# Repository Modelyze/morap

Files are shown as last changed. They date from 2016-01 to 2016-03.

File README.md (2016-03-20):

# MORAP: a Modular Robotic Arm Platform

### Contributors
* Viktor Kozma, KTH Royal Institute of Technology, vkozma@kth.se
* David Broman, KTH Royal Institute of Technology, dbro@kth.se

## Introduction
The MORAP system is designed to be a modular robotic arm for research purposes. It's modular in a way that modules can be designed and added or interchanged to achieve new configurations.

It is designed together with a Modelyze modeling library that allows building and simulating arm configurations, giving the user the ability to design and evaluate designs in software.

## Overall Design
The system is designed as a distributed system where each component is communicating on a standardized central data bus. This means that it's trivial to add other modules or sensors to the system.

The system has one master which controls all of the individual sub-systems and handles communication with the user. This master controller can be anything, a microcontroller, Arduino, Raspberry pi etc. The user programs this controller to fulfill specific tasks relevant to their intended application.

## Software Design
For actuation each joint have built in control electronics and tuning algorithms, providing an intuitive and easy way to control the system. The communication protocol is listed in [here](./api/) and an API implementation on a PIC32 microcontroller is listed in section [here](./api/pic32/).

Some software examples are listed [here](./applications).

## Hardware Design
The hardware is divided into joints, links and end-effectors. 

The joints provide actuation and control electronics, allowing the user to control them in multiple ways. There are also be free-running joints, like pendulums, which allows for modeling and controlling complex systems. The joints designs are found [here](./joints).

Links are the connection elements between the joints and can be anything. In this application 20x20 mm aluminum profiles are used. [possible pics?].

End-effectors are devices meant to interact with the real world. They're attached to the end of the arm and can come in different shapes, like pens or claws. Some designs can be found [here](./end-effectors).

The manufacturing process used to fabricate the necessary parts are 3d-printing.

## The Simplified BSD License

Copyright (c) 2016, Viktor Kozma and David Broman

All rights reserved.

Redistribution and use in source and binary forms, with or without
modification, are permitted provided that the following conditions are
met:

1. Redistributions of source code must retain the above copyright
notice, this list of conditions and the following disclaimer.

2. Redistributions in binary form must reproduce the above copyright
notice, this list of conditions and the following disclaimer in the
documentation and/or other materials provided with the distribution.

THIS SOFTWARE IS PROVIDED BY THE COPYRIGHT HOLDERS AND CONTRIBUTORS
"AS IS" AND ANY EXPRESS OR IMPLIED WARRANTIES, INCLUDING, BUT NOT
LIMITED TO, THE IMPLIED WARRANTIES OF MERCHANTABILITY AND FITNESS FOR
A PARTICULAR PURPOSE ARE DISCLAIMED. IN NO EVENT SHALL THE COPYRIGHT
HOLDER OR CONTRIBUTORS BE LIABLE FOR ANY DIRECT, INDIRECT, INCIDENTAL,
SPECIAL, EXEMPLARY, OR CONSEQUENTIAL DAMAGES (INCLUDING, BUT NOT
LIMITED TO, PROCUREMENT OF SUBSTITUTE GOODS OR SERVICES; LOSS OF USE,
DATA, OR PROFITS; OR BUSINESS INTERRUPTION) HOWEVER CAUSED AND ON ANY
THEORY OF LIABILITY, WHETHER IN CONTRACT, STRICT LIABILITY, OR TORT
(INCLUDING NEGLIGENCE OR OTHERWISE) ARISING IN ANY WAY OUT OF THE USE
OF THIS SOFTWARE, EVEN IF ADVISED OF THE POSSIBILITY OF SUCH DAMAGE.

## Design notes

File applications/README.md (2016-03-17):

# Applications using a PIC32 microcontroller

Some example applications using the PIC32 API. These applications are
implemented and tested on the ChipKIT UNO32 development board.

## Available applications
The following applications can be opened as MPLAB projects:

[Potentiometer control](./potentiometer_control) is a simple
application where a button can be used to turns on/off one or two
motors. Each motor can be controlled by a separate potentiometer.

[Draw test](./draw_test) performs a simple control sequence in which
it positions an optional pen end-effector at three different
angles. This allows the user to evaluate the repeatability of the
system and to identify potential drifts in the encoders. If two motors are
found on the system, it will use both for the control sequence.

[Data logger](./data_logger) generates log data that can be used for
parameter extraction.  When using the application, save the log data
data and run the appropriate [matlab
scripts](../joints/dc-motor-joint/software/matlab).

[Inverse kinematics](./inverse_kinematics) is an application for
controlling a 2D robotic arm with two joints. The user supplies an x-y
coordinate and it calculates the required angles to reach that
position. It also comes with an preliminary implementation of a path
following algorithm in which the user can define a path that the arm
should follow. This application is still work in progress.

[Inverted pendulum](./pendulum) is a work-in-progress application that tries to
balance an inverted pendulum. It utilizes a
MPU9150 IMU for measuring the angle of the pendulum and is
controlled by a state-feedback controller.

In most of the applications you can change some definitions to change the
identifiers of the target motors or the arm lengths. More information is available at the beginning of each main source file.

## Installation

To run the applications above, you need to download and install the following development environment and compiler:

* [MPLAB IDE](http://www.microchip.com/mplab/mplab-x-ide). This is the main development environment for the PIC32 microprocessors from Microchip.
* [XC32 compiler](http://www.microchip.com/mplab/compilers). The main cross compiler. There is a free compiler version available. NOTE! If you need to program the PIC24 controller on the motor joint, you also need to download the XC16 compiler.
* [PIC32 Peripheral Library](http://www.microchip.com/SWLibraryWeb/product.aspx?product=PIC32%20Peripheral%20Library). This library is necessary if you use XC32 compiler 1.4 or later.

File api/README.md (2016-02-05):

# APIs for Controlling the Robotic Arm

This section contains the API for controlling the robotic arm as well as information on how it works so it can be ported to other platforms.

## Available Applications
An API has been developed for a PIC32 processor, or more specifically the PIC32MX320F128 equipped on a uno32, an arduino compatible development board. This API can be found [here](./pic32).

## How it Works
The communication protocol works on an I2C bus [link to wiki?], a serial communication protocol, running at 100 kHz. The I2C protocol is a single master protocol in which a master can initiate communication and write or request data from an addressable slave. The system can address up to 128 different units (but in practice some of these are reserved resulting in 112 practical addresses), allowing for many different subsystems to be included on the bus. 

Each joint and end-effector has an unique address allowing the master to address individual modules. If the addressed slave exists and acknowledges its existence on the bus the master starts to write data to the slave one byte at a time. A master can also read data from a slave, however such a read operation is an individual event so the master usually has to specify what data it wants to read by writing that information to the slave before requesting a read operation.

As this is a standardized protocol peripheral hardware, for example sensors, can be easily included in the system.

## Communication Protocol
In order for the slave to know what type of data the master writes the first byte sent after the address is an identifier. For some commands, like disabling the motors or calibrating the encoders, only requires this identifier to take effect. If additional data is needed, for example setting reference points for the controller, it is provided after the identifier with data-types larger than one byte sent with LSB first [check].

When a read operation is performed on a node it will start to return data. But to define what data it will return by first writing the specified read-mode (id 128+ in the table below) before starting to request data.

A table containing the identifiers, their purpose and format (purpose(variable type)(nr of bytes)) (the identifier has the variable type (uint8)) are located below:

id | purpose | format 
---------: | :---------- | :----------- 
0   | disable motors | id(1) 
1   | set position reference point | id(1)-pos_ref(float)(4) 
2   | set speed reference point | id(1)-speed_ref(float)(4) 
3   | set drive voltage | id(1)-voltage(float)(4) 
14  | disable brake | id(1) 
15  | enable brake | id(1) 
16  | calibrate encoder to zero | id(1) 
17  | calibrate encoder to supplied angle | id(1)-angle(float)(4) 
31  | set encoder calibration status to unknown | id(1) 
32  | program new control parameters | see next section 
33  | set control parameters to default values | id(1) 
34  | tune control parameters | see next section 
128 | next read operation will return the angle (float(4)) | id(1) 
129 | next read operation will return the position reference (float(4)) | id(1) 
130 | next read operation will return the speed reference (float(4)) | id(1) 
131 | next read operation will return the motor status (byte(1)) | id(1) 
132 | next read operation will return the controller programming status (byte(1)) | id(1) 
133 | next read operation will return the applied voltage (float(4)) | id(1) 
134 | next read operation will return the current (float(4)) | id(1) 
136 | next read operation will return the address of the node (byte(1)) | id(1) 

Potential returns for the motor status are as follows:

return value | meaning
---------: | :---------
1 | enabled
2 | disabled
3 | needs encoder calibration

Potential returns for the controller programming status are:

return value | meaning
----------: | :------------
1 | nothing has been programmed
2 | programming successful
3 | programming failed

## Programming the Control Variables
The controller is described in the [matlab](../joints/dc-motor-joint/software/matlab) section. There are three different ways to program the controller with new control parameter.

Send the control parameters directly (id = 32). This is done by sending all the parameters containted in the discrete controller directly. The format looks like this: 
```
id(1) - cMode(uint8)(1) - Fs(uint16)(2) - nd(uint8)(1) - d(float[nd])(nd*4) - 
  nc(uint8)(1) - c(float[nc])(nc*4) - nf(uint8)(1) - f(float[nf])(nf*4) - 
  I(float)(4) - checksum(uint8)(1)
```

The checksum is calculated by the following psuedocode:
```c
unsigned int sum = sum(control_params); // the sum of all bytes sent (excluding the id)
while (sum >> 8)
  sum = (sum >> 8) + (sum & 0xFF);
unsigned char checksum = ~((unsigned char) sum);
```

This approach is useful when you want to really know what each joint are doing, for example when performing simulations that should be compared to reality.

The motor node can also tune themselves when provided with tuning variables (id = 34). The formatting of this message looks like:
```
id(1) - controller_type(uint8)(1) - inertia(float)(4) - closed_loop_pole(float)(4)
```

The controller type can be be one of the following values:

| value | controller |
| ---: | :--- |
| 0 | PD position controller |
| 1 | PID position controller |
| 2 | PI speed controller |

The inertia is the inertia that the controller designs itself around.

The closed loop pole is the pole of the controller which determines how fast the controller is. It should be < 0 and the smaller it is the faster the controller becomes.

After performing any of these commands read the programming status after to ensure that they where programmed successfully.

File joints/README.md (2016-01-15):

# Joints

Joints is in this regard the connections between each of the links.

## Connecting the Elements Together
These can be connected together in different way with the links.
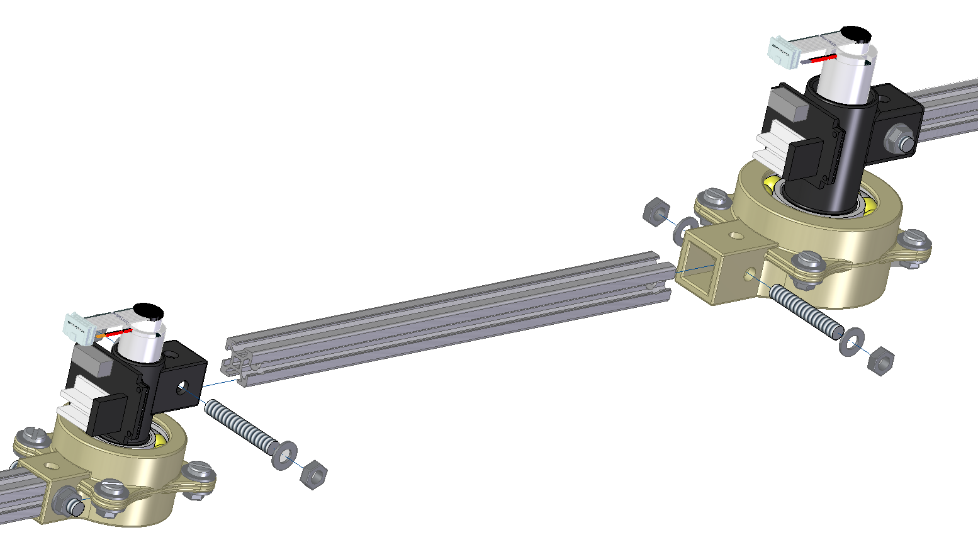
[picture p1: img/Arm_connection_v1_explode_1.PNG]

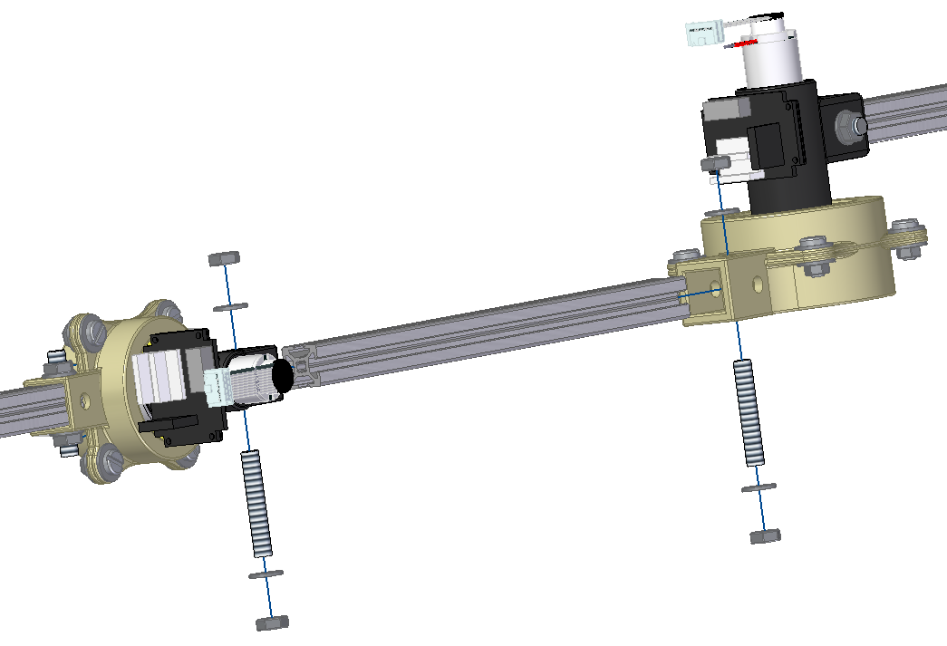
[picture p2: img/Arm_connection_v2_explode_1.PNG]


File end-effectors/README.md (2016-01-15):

# Different End Effectors Developed for the Robotic Arm

Contains different end-effectors capabale of mounting to the arm and interfacing with software.

## Making you own
**IMPORTANT. WHEN CONNECTING END EFFECTORS TO THE DATA BUS THE I2C LINES NEEDS TO WORK ON A 3.3 VOLT VOLTAGE LEVEL. OTHERWISE THE MOTOR CONTROLLING MICROCHIPS WILL BE FRIED.**  

This can be done through using chip that works on a 3.3 volt voltage level or using level shifters.

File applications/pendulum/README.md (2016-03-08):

# Inverted Pendulum

To get the inverted pendulum application up and running, please do the following.

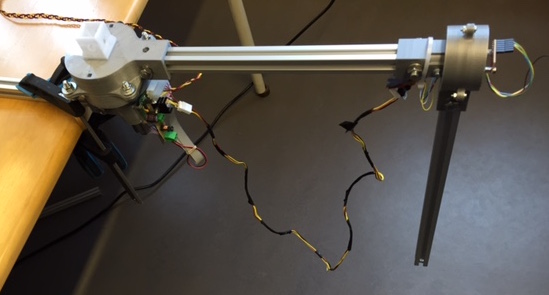
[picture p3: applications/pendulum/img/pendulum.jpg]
Example showing how the pendulum can be assembled
1. Connect one [motor joint](../../joints/dc-motor-joint) and a free-running [pendulum joint](../../joints/pendulum-joint) according to the picture below. 

2. Download and install the development environment ([see this page](../))

3. Open the project file applications/pendulum. Make sure that the project settings is correct and that you are using the right programmer (default is chipKITProgrammer).

4. Make sure that the supply voltage to the power is 24V. Reset the ChipKIT board and make sure that after the yellow LED is done blinking no LED should be lit up. If any of the leds are lit the following could be the issue:
    - Yellow LED stays lit: The I2C bus is hung up
    - Red LED stays lit: No connection to IMU found

5. Put the pendulum link in upright position. If the application works, the inverted pendulum should now stabilize. 

## Controller programming
A MATLAB script for generating control parameters are found [here](../../joints/dc-motor-joint/software/matlab) labeled "furuta_controller.m".

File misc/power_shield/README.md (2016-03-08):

# Power Shield for UNO32
A power shield designed to fit on an UNO32 designed to take input from two 4 mm lab cables, convert it to 5V and 3.3V and outputs it to two 6-pin connectors compatible with the standard connectors on the motor control chips.

Contains both Gerber and eagle source files

## Functions
* Inputs selectable voltage Vcc (>6V) through two 4 mm lab cables (Vcc and GND)
* Converts Vcc to 5V and 3.3V using two switching regulators
* Outputs Vcc, 5V, 3.3V, GND, SCL, SDA through a system standard 6 pin connector
* Contains pullup resistors for SCL and SDA line
* Contains two buttons connected to UNO32 pins 2 & 7 (RD8 & RD9)
* Contains three leds on UNO32 pins 3, 5 & 6 (RD0, RD1 & RD2) and one power LED.

## Schematic
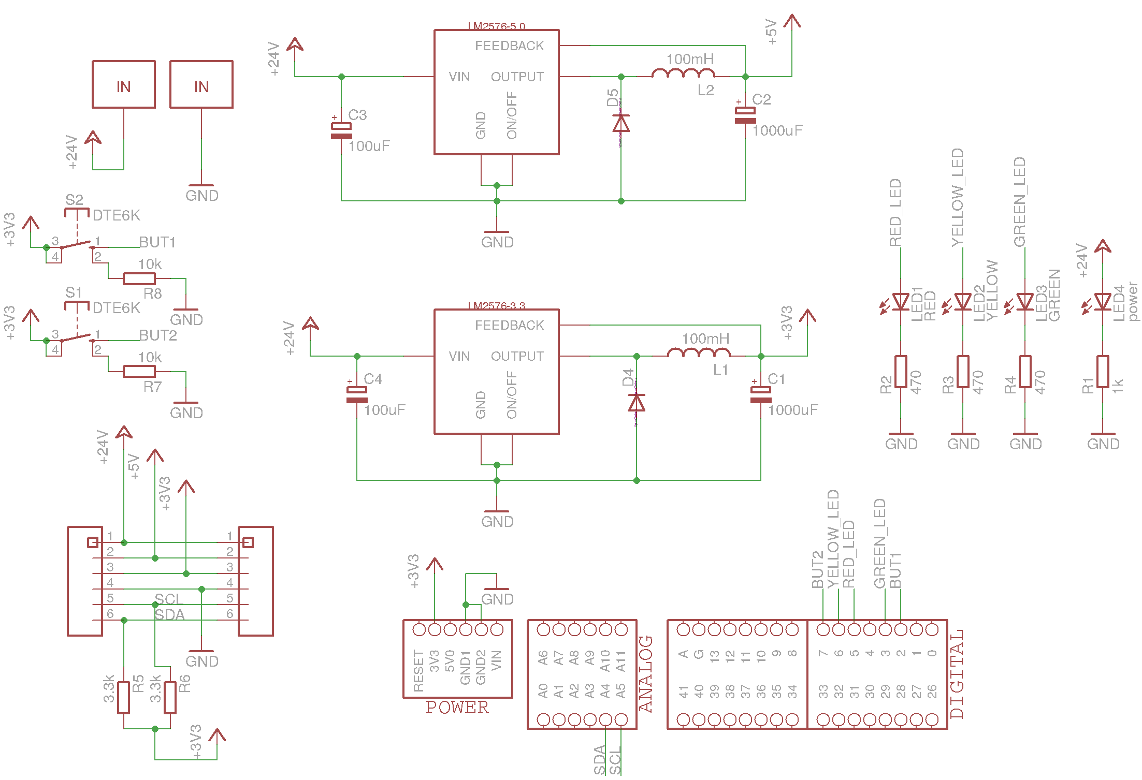
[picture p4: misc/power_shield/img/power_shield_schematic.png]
schematic


## Bill of Material
n | value | device | package
---: | :--- | :--- | :---
1x | LM2576-5.0 | Switch Regulator 5V | TO-220-5
1x | LM2576-3.3 | Switch Regulator 3.3V | TO-220-5
2x | 1000&mu;F | Electrolytic Capacitor | 10mm Electrolytic Capacitors SMD
2x | 100&mu;F | Electrolytic Capacitor | 10mm Electrolytic Capacitors SMD
2x |  | Diode | DO-214AA=SMB
2x | 0.1mH (+1.5A) | Inductor | Radial 5mm pitch
2x | RED | LED | CHIPLED_1206
1x | GREEN | LED | CHIPLED_1206
1x | YELLOW | LED | CHIPLED_1206
1x | 1k&Omega; | Resistor | R0603
3x | 470&Omega; | Resistor | R0603
2x | 3.3k&Omega; | Resistor | R0603
2x | 10k&Omega; | Resistor | R0603
2x | | Pushbutton | Through-Hole PCB-switch
2x | 2x8 pin | Socket Header | 2.54mm pitch, long legged socket header
1x | 2x6 pin | Socket Header | 2.54mm pitch, long legged socket header
1x | 1x6 pin | Socket Header | 2.54mm pitch, long legged socket header
2x | MOLEX 3.96mm 6p | male connector | MOLEX_3.96MM_6P
1x | RED | Laboratory Socket | 15.3mm pitch PCB
1x | BLACK | Laboratory Socket | 15.3mm pitch PCB

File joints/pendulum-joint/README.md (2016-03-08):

# Pendulum joint

The pendulum joint is a free-running joint (there is no DC motor). After it has been assembled, it can look like this:

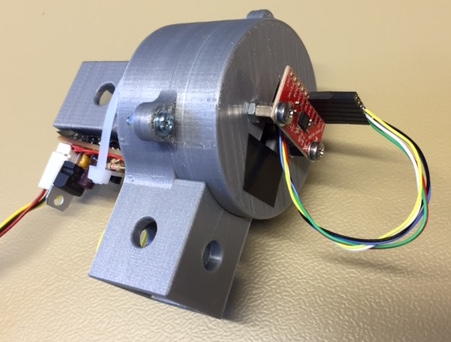
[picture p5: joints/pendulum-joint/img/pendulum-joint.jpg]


The joint consists of four 3D printed parts, a bearing (SKF 6205), an MPU9150 (gyro and
accelerometer), and a slip ring (22mm). All 3D models are available as .stl-files and as source files in Solid Edge format.

The following figure shows the CAD file when it is assembled
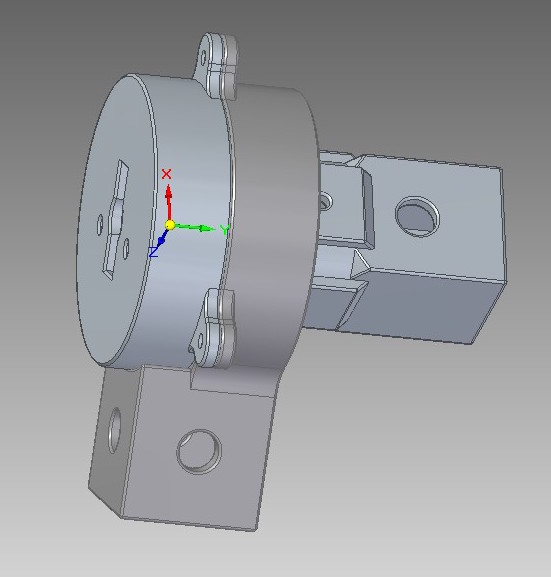
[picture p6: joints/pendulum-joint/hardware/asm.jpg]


and the following figure shows the exploded view of the parts
(excluding the slip ring).
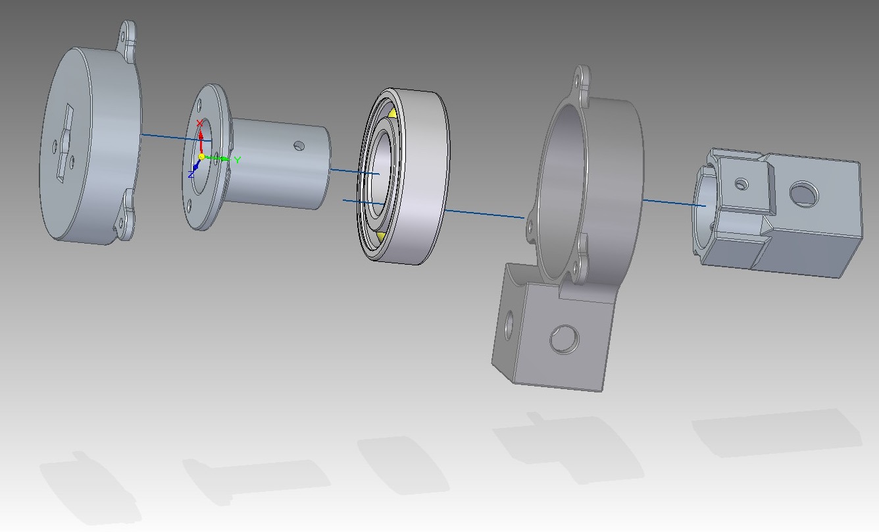
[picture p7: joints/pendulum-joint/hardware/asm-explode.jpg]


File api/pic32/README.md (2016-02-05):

# API for a PIC32 Microcontroller
This is an api with an implementation of the motors on a pic32 microcontroller.

This api contains two parts, I2C drivers for the PIC32 and drivers for using this library to communicate with the motors. It also contains drivers for individual end-effectors.

Also, if using the uno32 development board jumper JP6 and JP8 needs to be set to the lower position as visualized below. This is to connect the I2C lines to the chip.

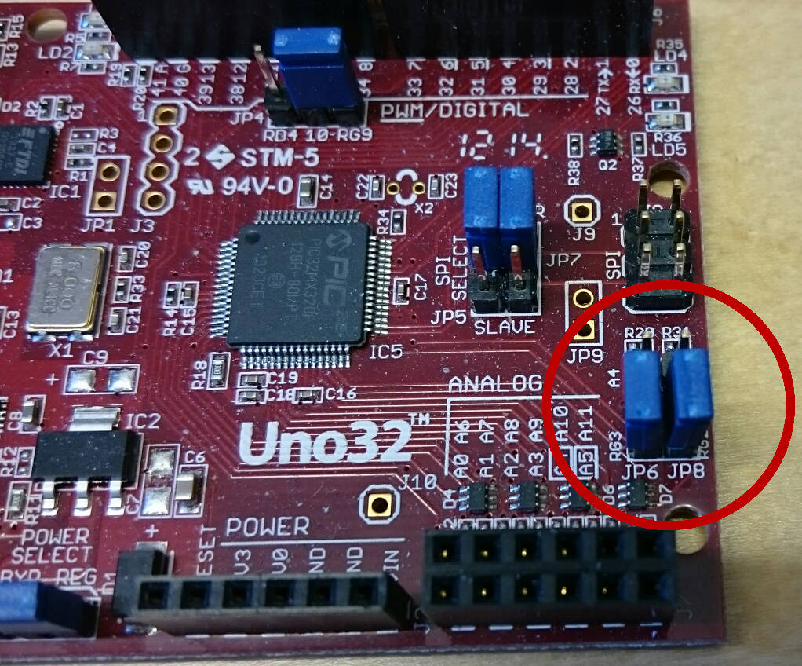
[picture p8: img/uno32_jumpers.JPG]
uno32 jumpers


## How to Use
Include `modular_arms.h`  into your project:
```c
#include "modular_arms.h"
```
Initiate the arm by calling:
```c
init_arm(GetPeripheralClock());
```
Where `GetPeripheralClock()` is a macro defining the peripheral clock speed in Hz.

When the arm is initiated you can start issuing commands to it.

Before the arm can start being controlled the encoders of each individual motors needs to be calibrated so they know what physical direction corresponds to what angle. This is done by (for each motor on the arm) calling:
```c
calibrate_encoder_zero(node_id);
```
Where `node_id` is a variable corresponding to the id-number of the motor you want to calibrate. Each individual motor has it's unique id ranging from 0 to 7. When calling this the node assumes that you have physically oriented the motors to point in the direction you want to define as having an angle of 0 radians.

When all the motors are calibrated they can start being used. There are several ways to control these motors, the most useful being the position control. To position a motor at a specific angle you can call:
```c
set_angle(node_id,target_angle);
```
Where `target_angle` is the angle radians at which the motor positions itself.

There's also a built in speed feedback controller which can be called by:
```c
set_angular_velocity(node_id,target_angular_speed);
```
Where `target_angular_speed` is the angular speed in radians/second which the motor will rotate at.

You can read variables and status messages from the node in a similar way. For example to get the current angle of the motor you can call:
```c
float current_angle;
get_angle(node_id,&current_angle);
```
This allows you to monitor the current motor position, useful when using the speed input to avoid going out of bounds.

When done controlling the arm the motors can be disabled by calling:
```c
disable_motor(node_id);
```
This turns them of and allows you to rotate the motor freely. 

To re-enable the motors just run a `set_angle` or `set_angular_velocity` command and it will enable the motors and fulfill that command.

If you don't want the motor to rotate at all when disabled a brake can be activated by calling:
```c
enable_brake(node_id);
```
This shorts the leads of the motors, providing high resistance against turning. This will automatically be disabled when the motors are re-enabled, forcing you to reactivate it the next time they're disabled.

Alternatively the motors can be turned off by setting the encoder status of the motors to unknown by calling:
```c
set_calibration_status_unknown(node_id);
```
This requires you to recalibrate the encoders when activating it again later.

## Tuning the control algorithm
To improve the performance of the feedback controller it sometimes has to be tuned for its intended applications. As the default programmed controller on each of the nodes are optimized around a low inertia they may not operate to their full capacity when they drive a high inertia. So for applications where a motor is supposed to drive a high inertia (for example the first joint of an arm) the controller can be tuned by calling:
```c
tune_control_params(node_id,TUNING_PD_POSITION_CONTROLLER,TUNING_MEDIUM_INERTIA,TUNING_POSITION_POLE_MEDIUM);
delay(50); // small delay so the controller has time to calculate the new variables
unsigned char prog_status;
get_control_prog_status(node_id, &prog_status);
if (prog_status == MOTOR_CONTROL_PROGRAMMING_STATUS_SUCCESS) {
  //SUCCESS
}
```
Some common inertias are predefined and should serve well.

Two different position controllers are available for tuning, these are:
```
TUNING_PD_POSITION_CONTROLLER
TUNING_PID_POSITION_CONTROLLER
```
For most positioning tasks a PD controller is sufficient and more robust than a PID-controller. However certain situations, like vertically mounted arms, requires a PID-controller to get rid of steady state errors. 

To tune the speed controller you can similarily call:
```c
tune_control_params(node_id,TUNING_PI_SPEED_CONTROLLER,TUNING_MEDIUM_INERTIA,TUNING_SPEED_POLE_MEDIUM);
delay(50); // small delay so the controller has time to calculate the new variables
unsigned char prog_status;
get_control_prog_status(node_id, &prog_status);
if (prog_status == MOTOR_CONTROL_PROGRAMMING_STATUS_SUCCESS) {
  //SUCCESS
}
```
This will tune the speed controller that is called when using the command `set_angular_velocity()`, allowing you to fine tune responses.

The default controller parameters can be recalled using the command:
```c
set_default_control_params(node_id);
```

## Compatability
This api has been developed for a the PIC32MX320F128 microcontroller equipped on a uno32, an arduino compatible development board. It should work on similar microcontrollers but it hasn't been tested.

Technically the modular_arms.h and modular_arms.c should work with any systems as long as the i2c drivers are available. The required functions are:
```c
unsigned char TransmitData(unsigned char address, unsigned char* data, unsigned char datasize);
unsigned char ReadData(unsigned char address, unsigned char* data_bufger, unsigned char datasize);
unsigned char PokeAddress(unsigned char address);
```

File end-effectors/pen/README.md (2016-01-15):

# A Pen End Effector
This is a simple pen end effector designed around a standardized servo. Designed for 3d-printing.

## Bill of Materials
* Standard servo
* Pen
* 4x M4 screws (10mm)
* 4x M4 nuts
* 2x M3 screws (10mm)
* 2x M3 nuts
* 4x M2 screws (6mm)

## Some Pictures
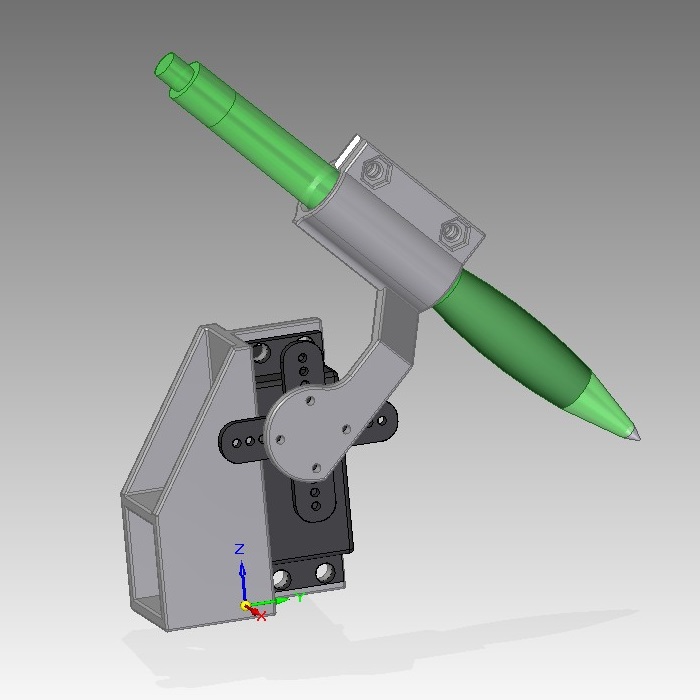
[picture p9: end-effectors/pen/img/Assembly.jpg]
Assembled in Solid Edge

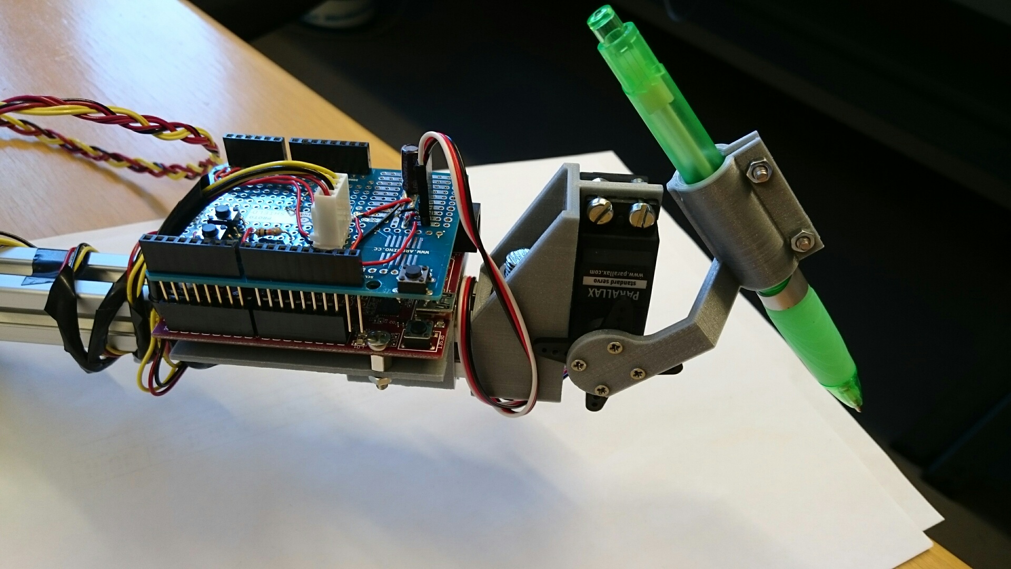
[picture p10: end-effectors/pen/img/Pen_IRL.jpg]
Real life pen


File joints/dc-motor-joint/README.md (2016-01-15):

# DC-Motor Joints

These are joints designed around brushed dc-motors equipped with encoders. Each motor joint comes equipped with it's own electronics and software for controlling the motors and communication.

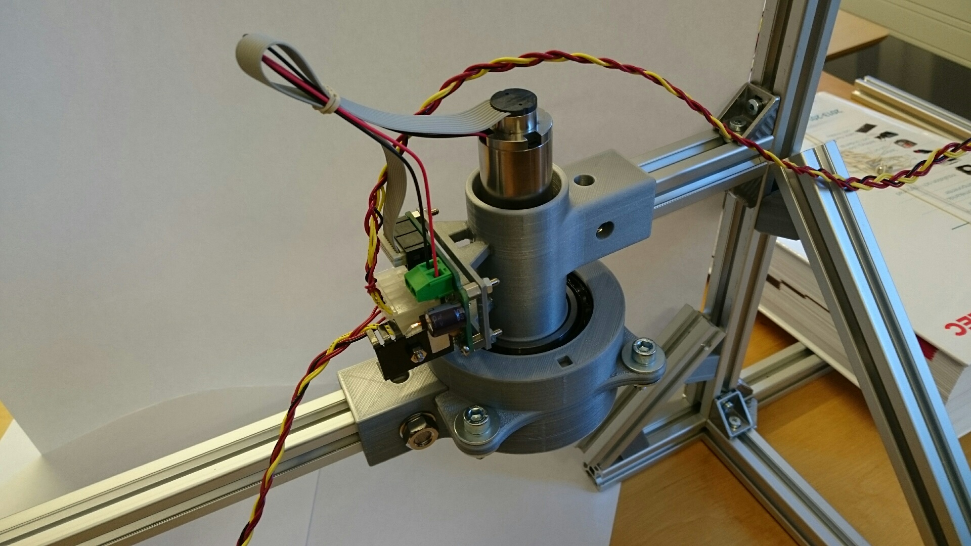
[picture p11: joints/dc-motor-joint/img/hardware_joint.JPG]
assembled joint


## Motors
The motors these joints are designed around comes from the DCX range of Maxon Motors.
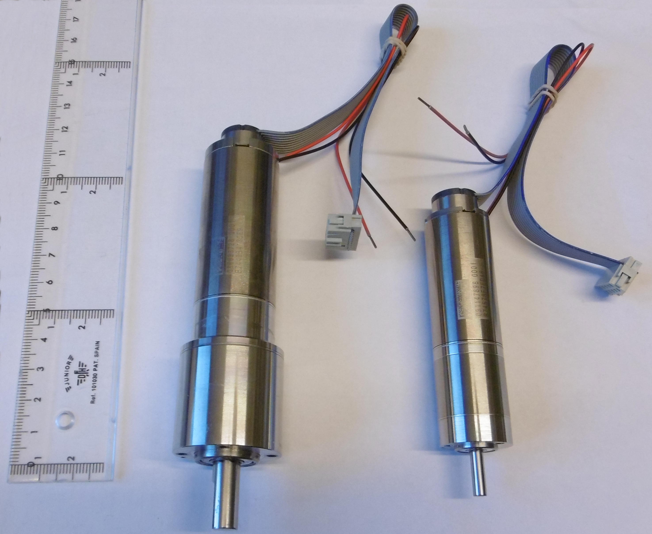
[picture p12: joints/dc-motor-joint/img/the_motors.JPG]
The motors

(Link to configuration specifications or drawings for measurements). Two joints are then designed around each of these motors.

Technically any brushed dc-motor supplied with an encoder are possible to use but that requires redesign with new measurements of one of the existing joints.

## Hardware and Manufacturing
The hardware are located [here](./hardware) both as stl files as well as the source code.

The manufacturing process used to build the hardware is 3d-printing.

## Electronics
The design of the controlling electronics are located [here](./electronics). It is based on a pic24 microcontroller and a LMD1800 motor driver with connections to both motor and encoder.

It contains gerber files for pcb manufacturing, source files for eagle. It also contains source files for a uno32 power shield intended for use on a master controller.

## Software
The software for controlling the motors are located [here](./software). This includes source code for the pic24 microcontroller as well as MATLAB code used to derive controller parameters, extract parameters from the hardware used for modeling and system simulations.

## On-board LED Functionality
Each electronic board is equipped with two leds, one green and one red.

The possible blinking messages for the red led are:

| period | duty cycle | meaning |
| ---: | ---: | :--- |
| 1 sec | 20% | The encoder needs calibration |
| 3 sec | 50% | Error reading from the EEPROM data |
| &infin; sec | 100% | Motor controller is overheated | 

When none of these conditions above are present the red led will flash with a period the same as the current sampling rate of the controller and have a duty cycle equal to the cpu utilization of the timer interrupt.

The default mode of the green led is to blink each time it receives an I2C-message but can be changed to other modes in the source code.

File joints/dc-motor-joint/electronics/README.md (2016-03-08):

# The electronics
This part contains the electronics used for 

A completed breadboard looks like:
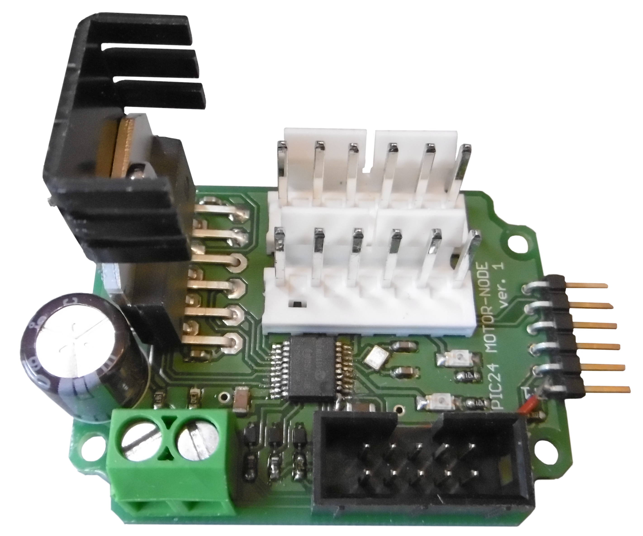
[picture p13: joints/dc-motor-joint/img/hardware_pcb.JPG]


## Schematic
The following is the schematic for the node:
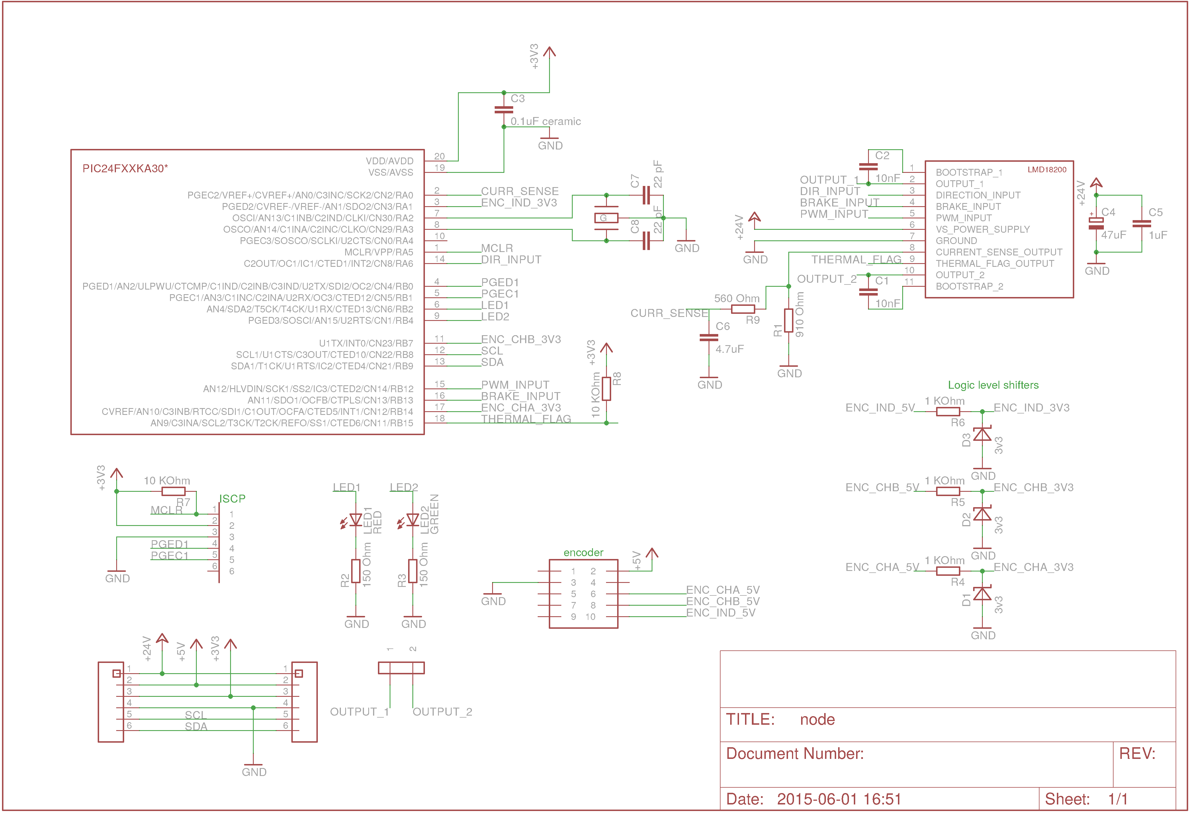
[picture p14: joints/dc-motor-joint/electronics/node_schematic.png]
node schematic


## Bill of Material for Node
n | value | device | package
---: | :--- | :--- | :---
2x | 10nF | capacitor | C0603
1x | 0.1&mu;F ceramic | capacitor | C0805K
1x | 0.1&mu;F | capacitor | E5-10,5
1x | 1&mu;F | capacitor | C050-025X075
1x | 4.7&mu;F | capacitor | C0805K
2x | 22pF | capacitor | C0603
3x | 3v3 | zener diode | SOD-323 
1x | RED | LED | CHIPLED_1206
1x | GREEN | LED | CHIPLED_1206
1x | 910&Omega; | Resistor | R0603
2x | 150&Omega; | Resistor | R0603
3x | 1k&Omega; | Resistor | R0603
2x | 10k&Omega; | Resistor | R0603
1x | 560&Omega; | Resistor | R0603
1x | 32MHz | crystal | [SMD](https://www.elfa.se/en/quartz-smd-32-mhz-iqd-lfxtal052187r500/p/17451988)
1x | PIC24F32KA301 | &mu;C | SSOP-20
1x | LMD18200 | motor controller | TO-220-11
2x | MOLEX 3.96mm 6p | male connector | MOLEX_3.96MM_6P
1x | DIN41651 10P | encoder connector | DIN41651_10P
1x | 2x5.08P | screw block | 2x5.08P
1x | 6x1 pin header | pin header | 6X1P 2.54mm pin header

## Cables
The cabling between each node has a female 6 pin connector with 3.96mm raster in each end.

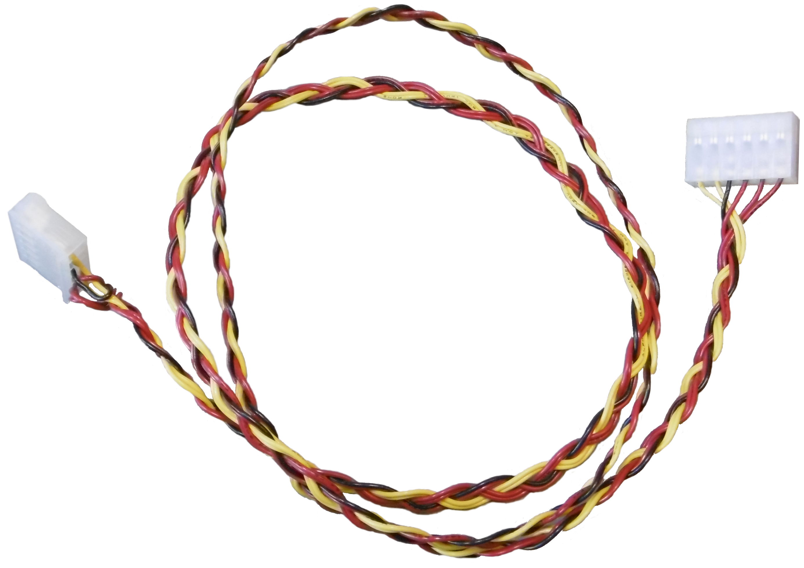
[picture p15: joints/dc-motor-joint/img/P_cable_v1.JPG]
cable


## Additional Electronics
An early version of an improved node board is also located here. This includes numerous improvements, such as using an LM339 voltage comparator to provide a more robust interface for reading the encoder. Another intended improvement is zoning which aims to isolate the motor driver from the rest of the circuit, which should reduce the electrical noise plaguing the current version.

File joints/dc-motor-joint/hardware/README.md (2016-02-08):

# DC-motor Joint Hardware
This contains designs for two different joints. One centered around a [22mm circumference gearbox](./22mm_joint) and one centered around a [32mm circumference gearbox](./32mm_joint).

[Misc](./misc) contains miscellaneous files used generally throughout the system.

[22mm_joint](./22mm_joint) contains a joint designed around a Maxon GPX22 gearhead which has the following dimensions:
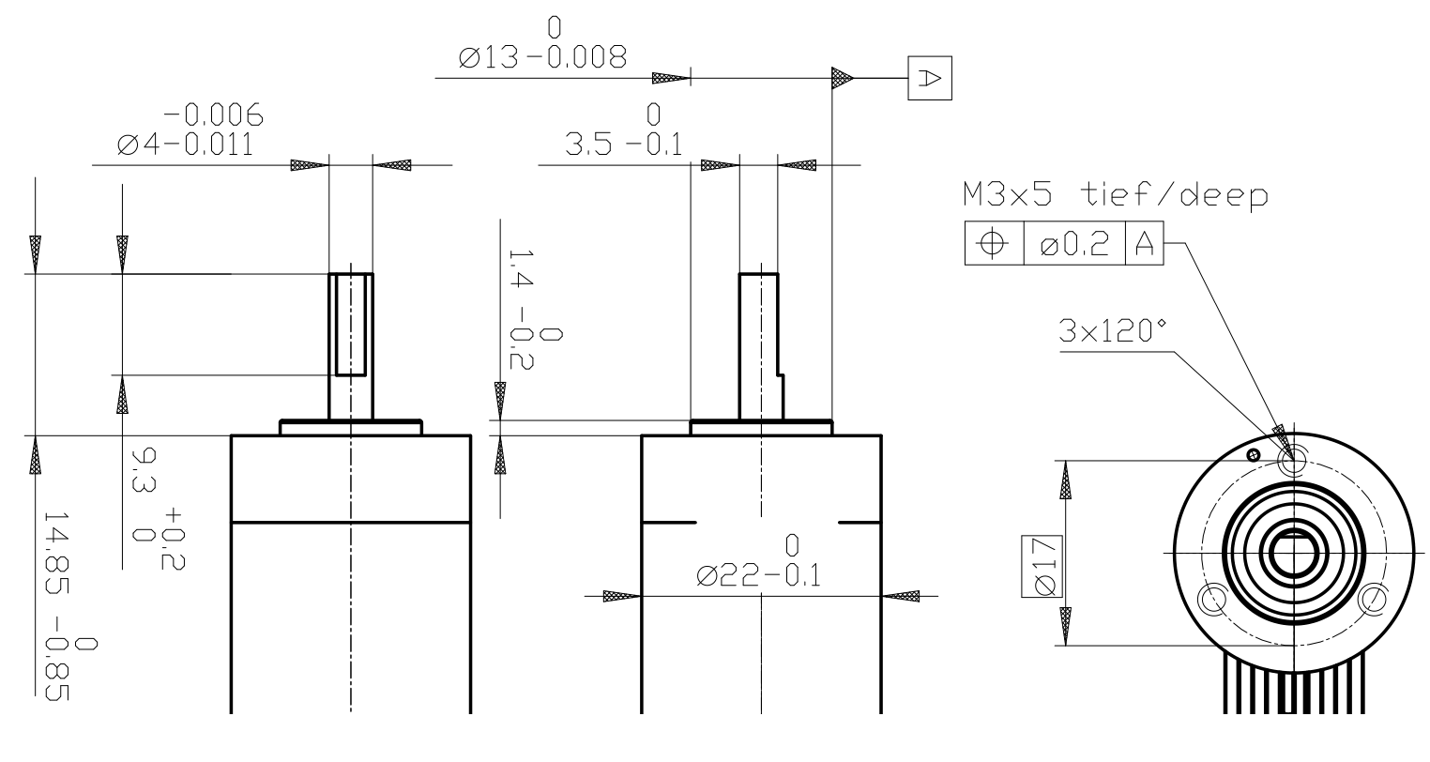
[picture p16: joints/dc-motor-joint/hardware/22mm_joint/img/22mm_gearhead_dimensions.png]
gpx22 dimensions


[32mm_joint](./32mm_joint) contains a joint designed around a Maxon GPX32 gearhead which has the following dimensions:
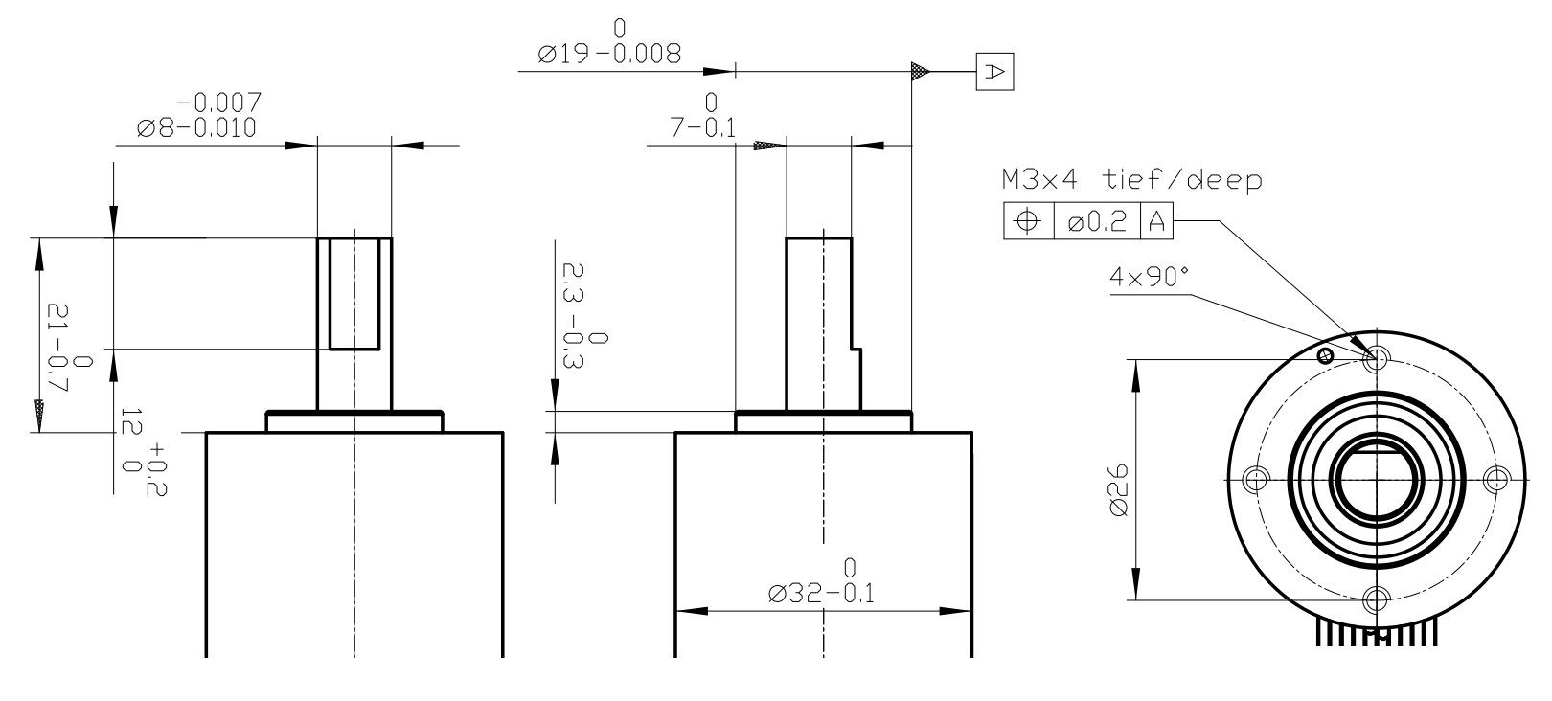
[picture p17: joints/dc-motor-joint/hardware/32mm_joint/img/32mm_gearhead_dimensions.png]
gpx32 dimensions


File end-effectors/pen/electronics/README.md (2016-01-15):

# Electrical Schematics

When designed around an uno32 this schematic is used:

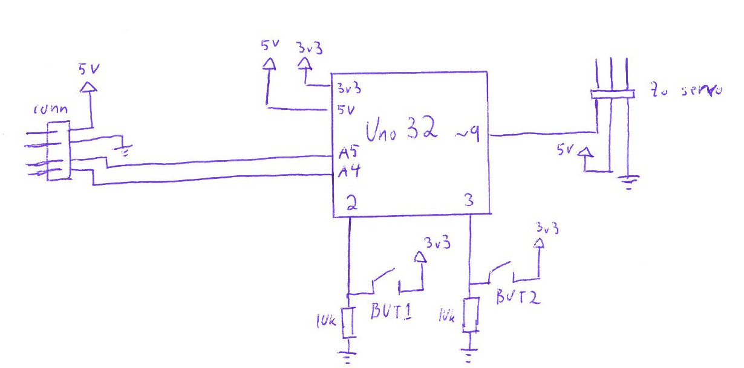
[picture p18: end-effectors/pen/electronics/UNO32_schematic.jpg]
uno32 schematic


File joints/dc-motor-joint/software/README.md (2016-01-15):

# Software

This section includes source code for controlling the motors, [here](./pic24-motor-controller) as well as [matlab code](./matlab) used for control parameter generation, modeling parameter extraction from log files and system simualtions.

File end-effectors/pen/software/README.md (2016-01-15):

# Software for the Pen End Effector

For programming the boards: For chipkit boards (like the uno32) use MPIDE, for arduino board use their IDE.

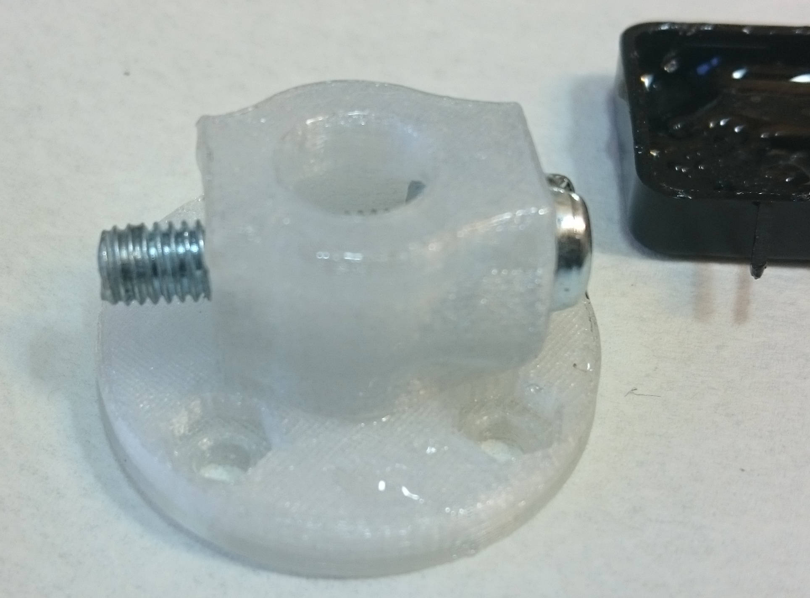
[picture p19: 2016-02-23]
joints/dc-motor-joint/hardware/32mm_joint/img/Shaft_attach_2.JPG

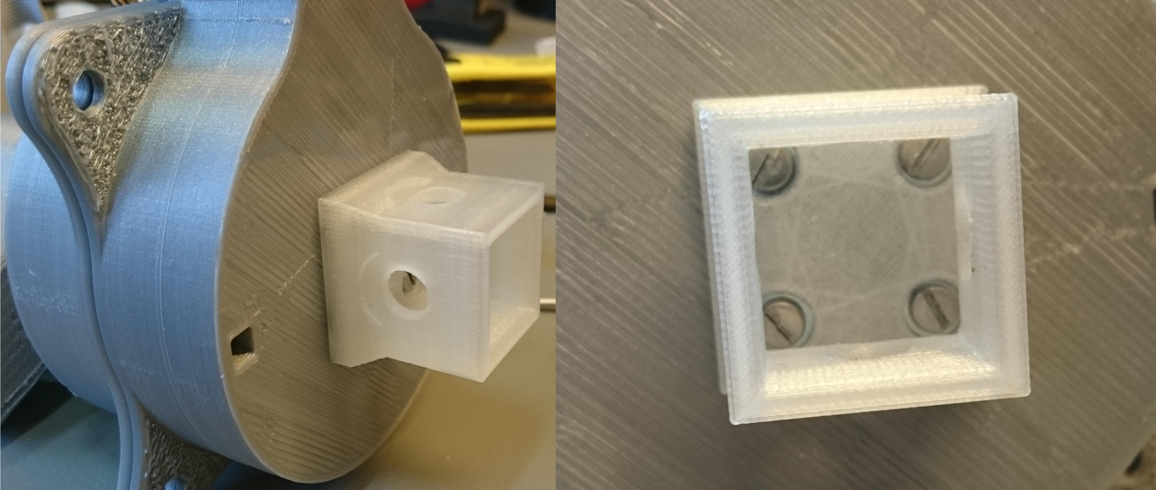
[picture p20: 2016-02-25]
joints/dc-motor-joint/hardware/32mm_joint/img/Shaft_attach_4.JPG

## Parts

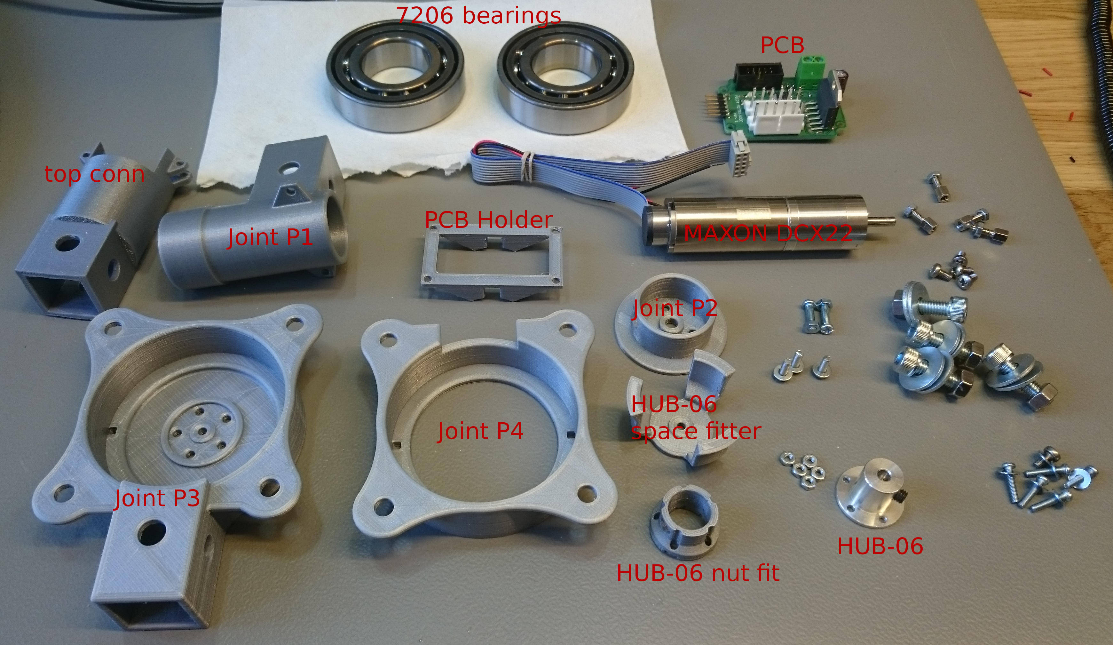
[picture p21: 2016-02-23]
joints/dc-motor-joint/hardware/22mm_joint/img/Assembly_Parts_Labeled.JPG

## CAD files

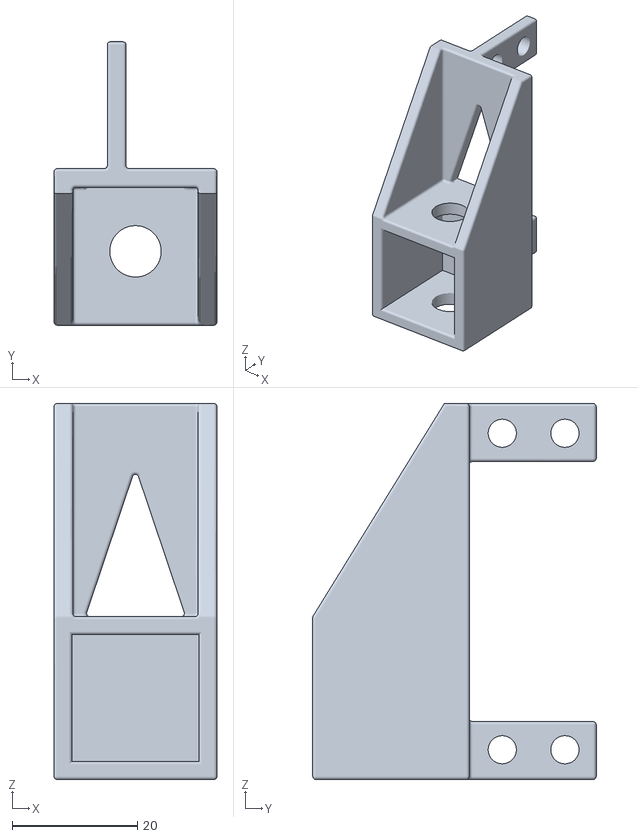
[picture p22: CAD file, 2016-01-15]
end-effectors/pen/cad/pen_base.stl
26.0 x 45.2 x 60.0

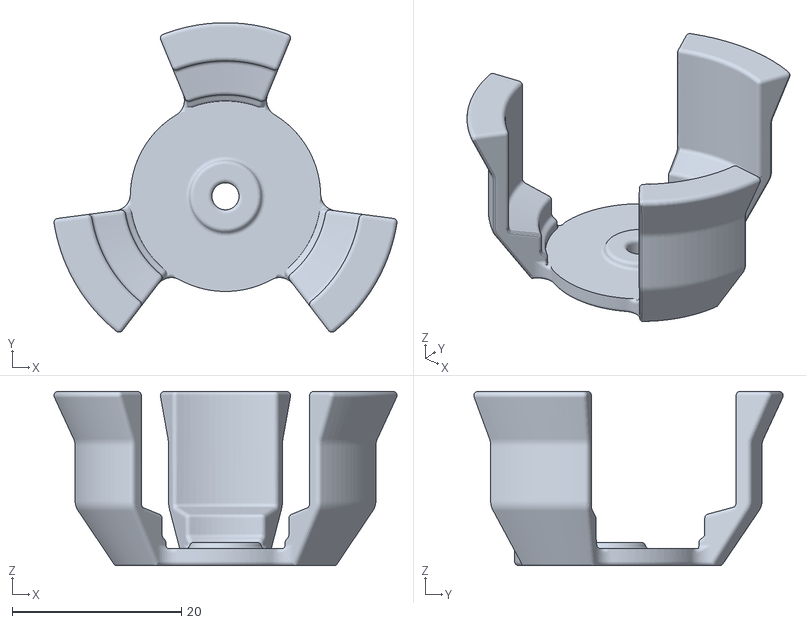
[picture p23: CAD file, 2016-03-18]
joints/dc-motor-joint/hardware/22mm_joint/HUB-06_space_fitter.stl
40.5 x 36.6 x 20.6

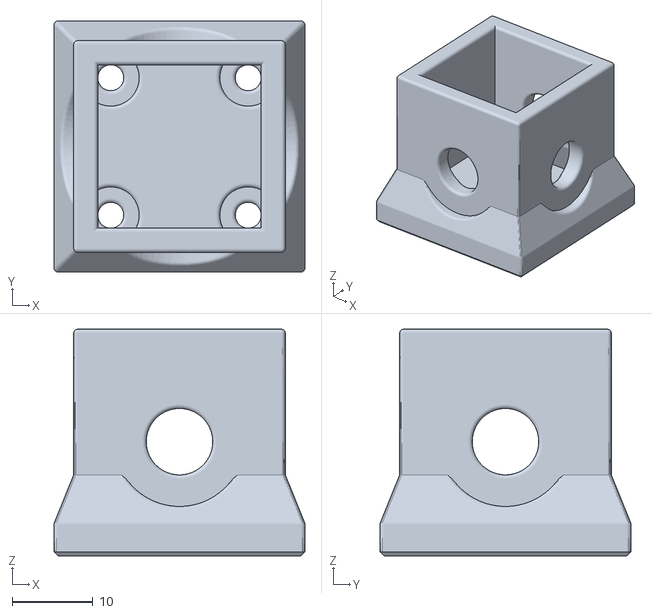
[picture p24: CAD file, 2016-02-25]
joints/dc-motor-joint/hardware/32mm_joint/32mm bottom_conn.stl
31.0 x 31.0 x 28.0

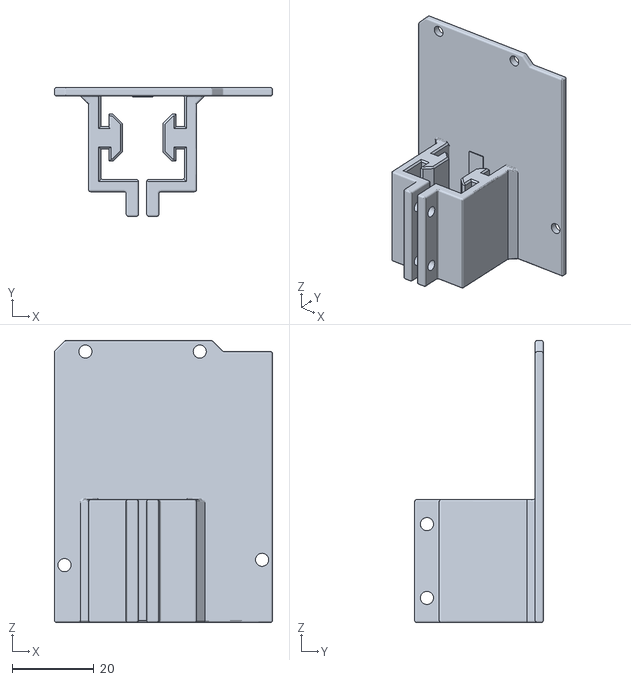
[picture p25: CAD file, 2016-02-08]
joints/dc-motor-joint/hardware/misc/general_purpose/arduino_holder.stl
53.3 x 31.4 x 68.8

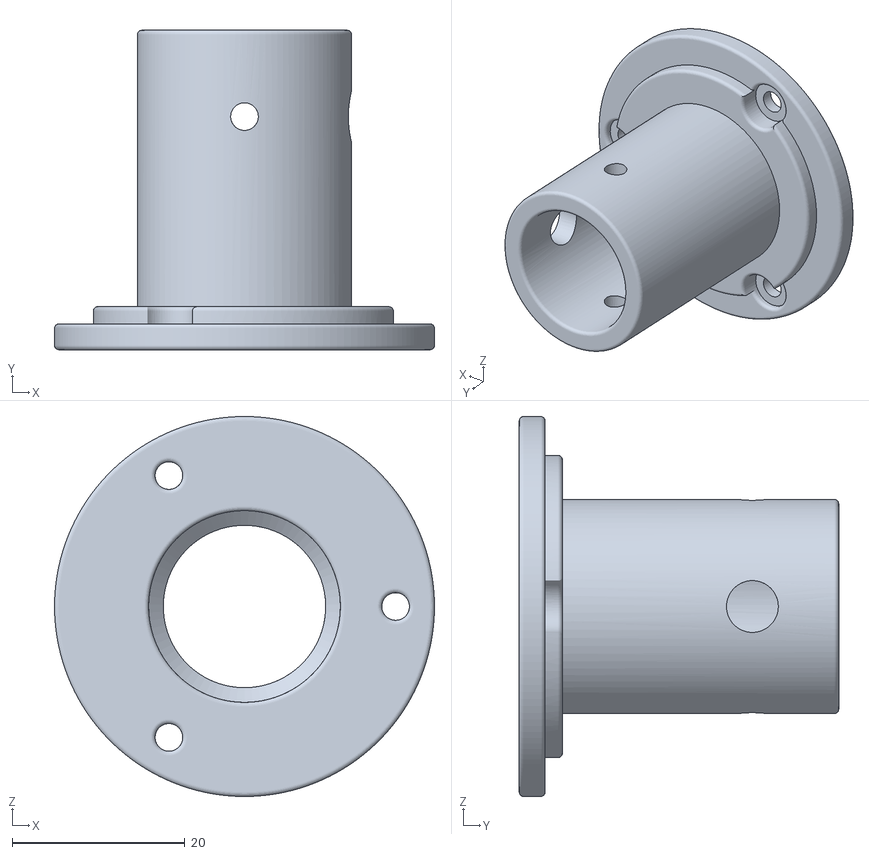
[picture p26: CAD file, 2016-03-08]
joints/pendulum-joint/hardware/inner-left.stl
44.0 x 37.0 x 44.0

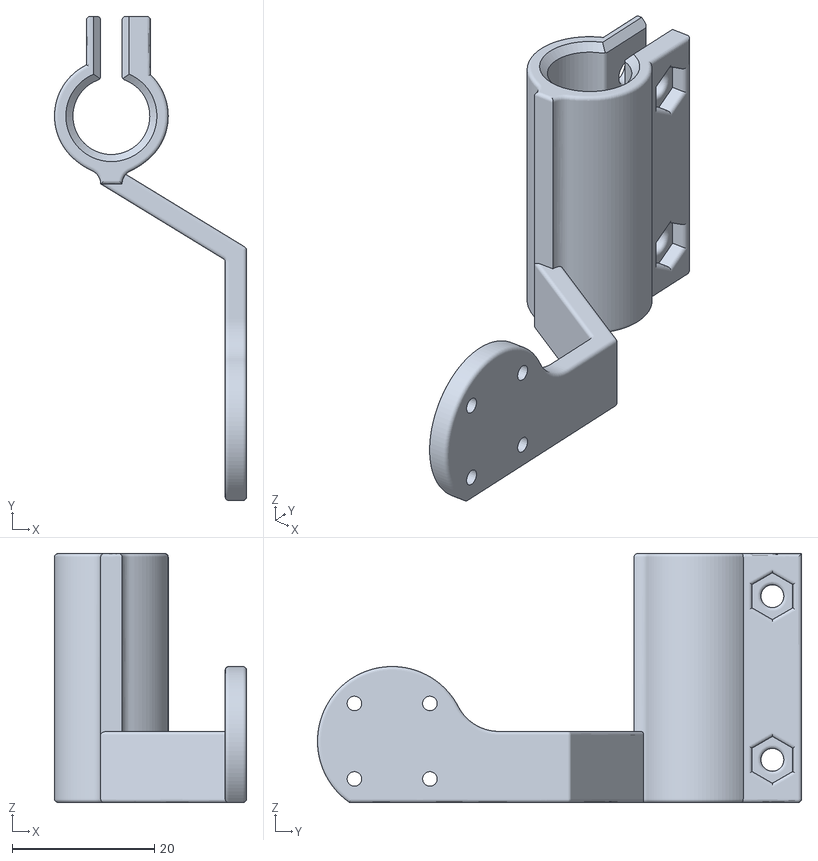
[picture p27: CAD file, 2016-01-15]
end-effectors/pen/cad/pen_holder_10mm8.stl
27.0 x 68.0 x 35.0

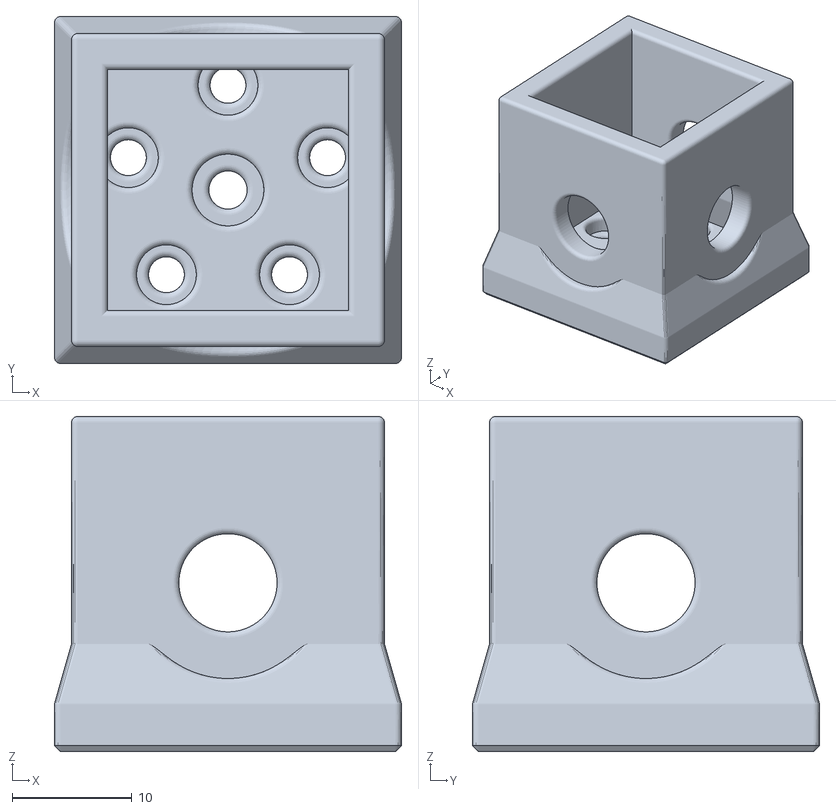
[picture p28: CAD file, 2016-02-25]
joints/dc-motor-joint/hardware/22mm_joint/22mm bottom_conn.stl
29.0 x 29.0 x 28.0

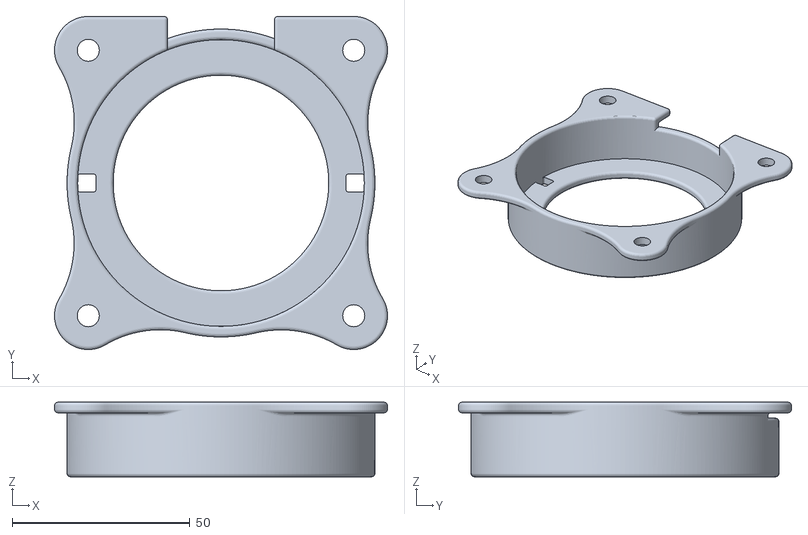
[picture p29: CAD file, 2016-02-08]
joints/dc-motor-joint/hardware/32mm_joint/32mm Joint P4.stl
93.7 x 93.7 x 21.0

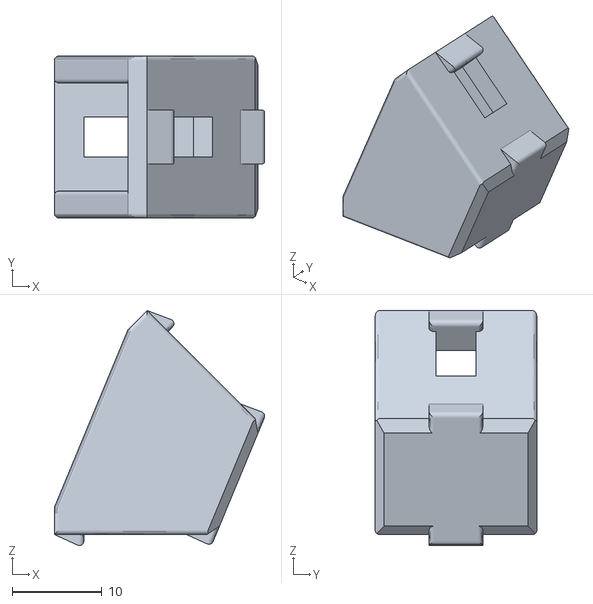
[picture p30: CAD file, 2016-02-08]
joints/dc-motor-joint/hardware/misc/general_purpose/45_degree_20x20_bracket.stl
23.4 x 18.0 x 26.1

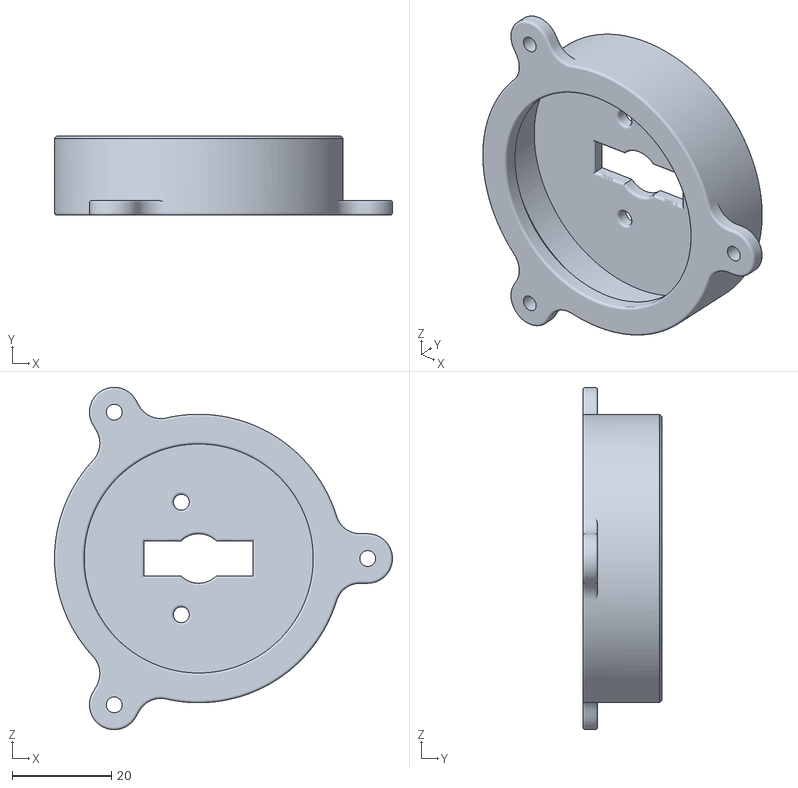
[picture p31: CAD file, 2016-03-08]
joints/pendulum-joint/hardware/outer-left.stl
68.2 x 16.0 x 69.1

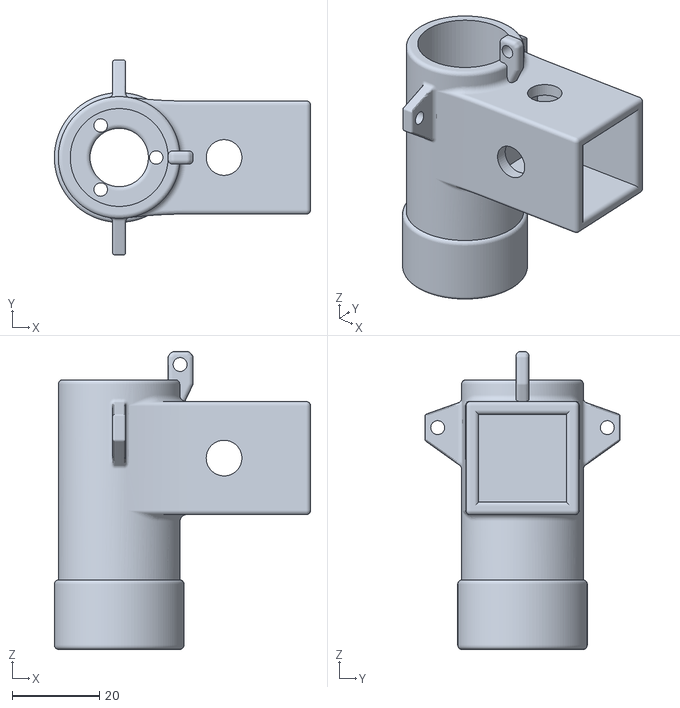
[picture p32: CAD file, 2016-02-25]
joints/dc-motor-joint/hardware/22mm_joint/22mm Joint P1.stl
58.9 x 44.8 x 68.5

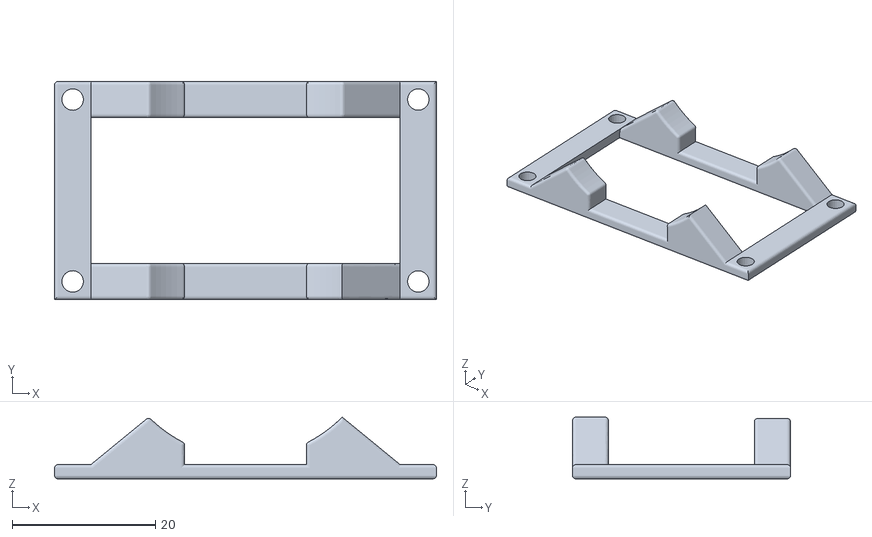
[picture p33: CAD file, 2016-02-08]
joints/dc-motor-joint/hardware/32mm_joint/32mm PCB_holder.stl
53.3 x 30.5 x 8.63

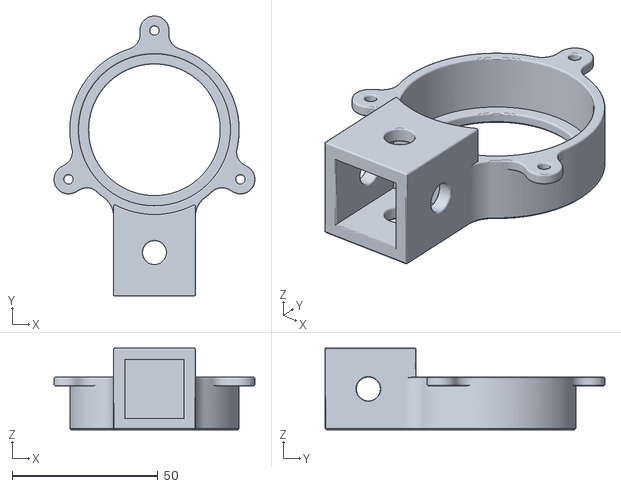
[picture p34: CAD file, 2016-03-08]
joints/pendulum-joint/hardware/outer-connect.stl
69.1 x 96.2 x 28.2

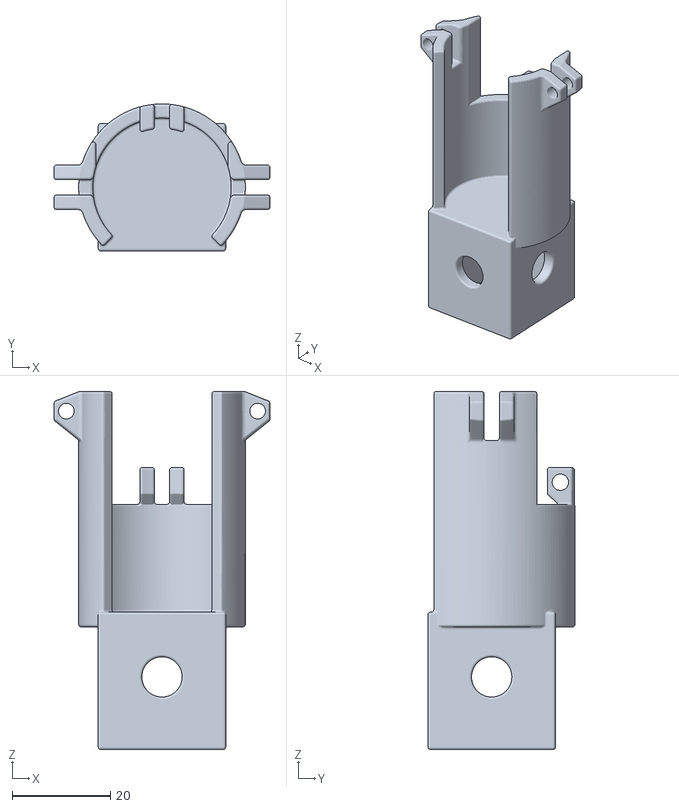
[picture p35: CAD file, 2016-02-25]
joints/dc-motor-joint/hardware/22mm_joint/22mm top_conn.stl
44.0 x 30.0 x 73.0

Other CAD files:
end-effectors/pen/cad/arduino_holder.stl
joints/dc-motor-joint/hardware/32mm_joint/32mm Joint P3.stl
joints/pendulum-joint/hardware/shaft-connect.stl
joints/dc-motor-joint/hardware/22mm_joint/22mm Joint P3.stl
joints/dc-motor-joint/hardware/22mm_joint/22mm Joint P2.stl
joints/dc-motor-joint/hardware/22mm_joint/22mm Joint P4.stl
joints/dc-motor-joint/hardware/22mm_joint/22mm PCB_holder.stl
joints/dc-motor-joint/hardware/22mm_joint/HUB06 nut fit.stl
joints/dc-motor-joint/hardware/32mm_joint/32mm Joint P1.stl
joints/dc-motor-joint/hardware/32mm_joint/32mm Joint P2.stl
joints/dc-motor-joint/hardware/32mm_joint/8mm_extra_nut.stl
joints/dc-motor-joint/hardware/32mm_joint/8mm_shaft_attach.stl

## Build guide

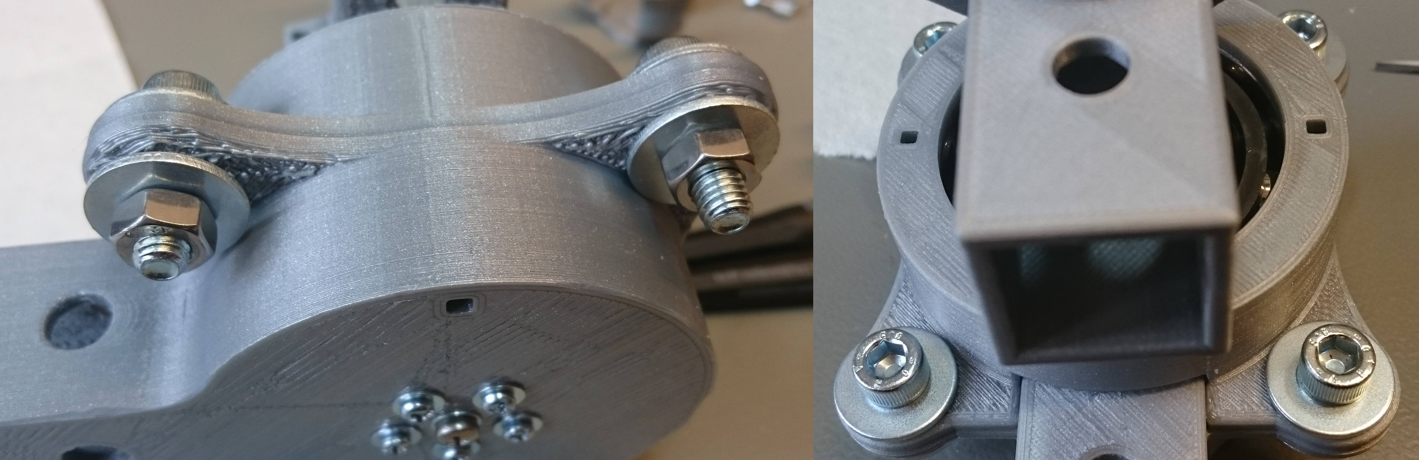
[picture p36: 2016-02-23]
joints/dc-motor-joint/hardware/22mm_joint/img/Assembly_6.JPG

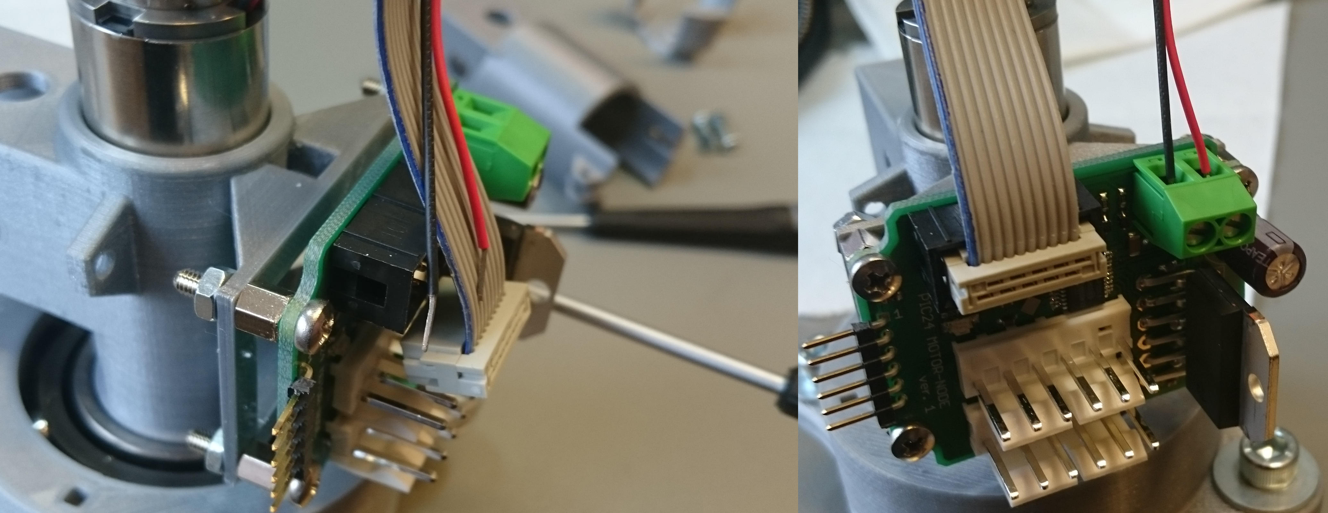
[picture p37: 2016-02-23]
joints/dc-motor-joint/hardware/22mm_joint/img/Assembly_7.JPG

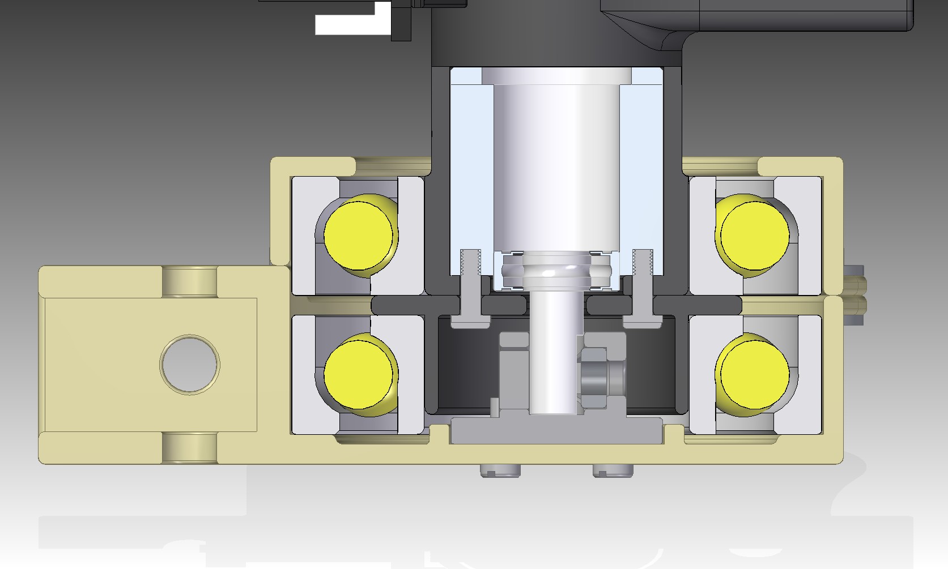
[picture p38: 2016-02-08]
joints/dc-motor-joint/hardware/32mm_joint/img/32mm_joint_assembly_cutout.jpg

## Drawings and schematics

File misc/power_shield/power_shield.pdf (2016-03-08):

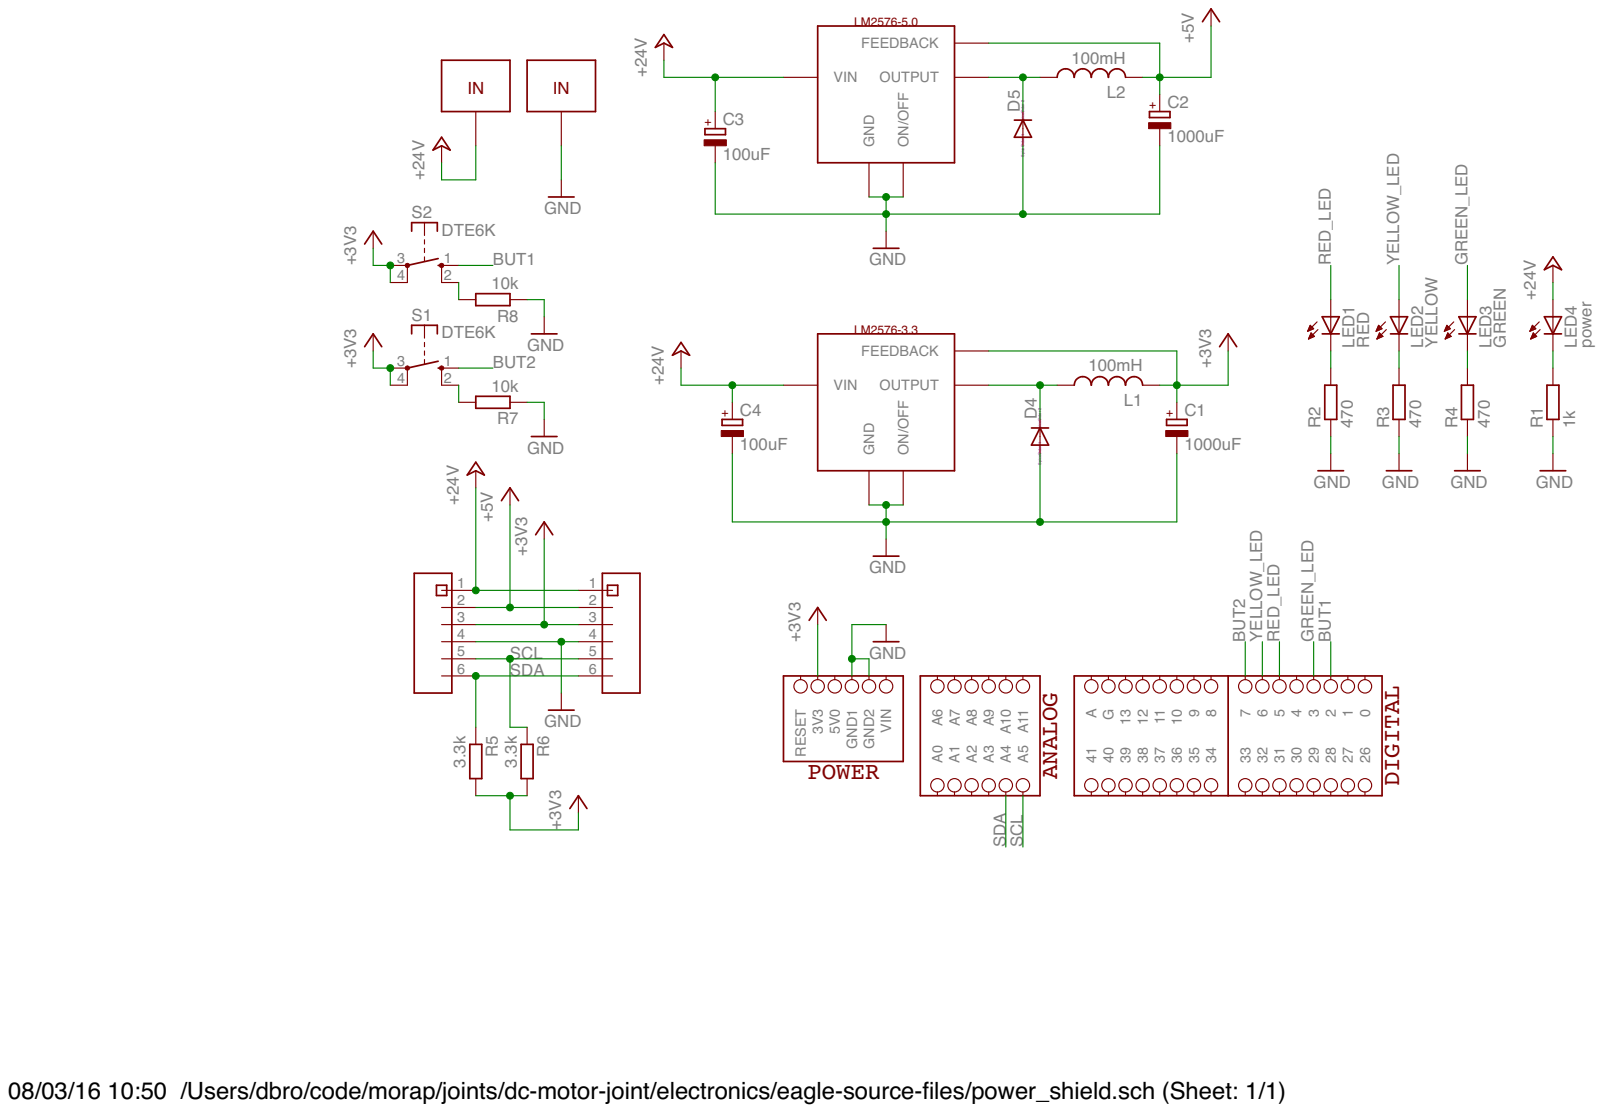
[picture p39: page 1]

GND ON/OFF VIN

SpiceOrder 1 SpiceOrder 2 SpiceOrder 1 SpiceOrder 2 100mH

08/03/16 10:50 /Users/dbro/code/morap/joints/dc-motor-joint/electronics/eagle-source-files/power_shield.sch (Sheet: 1/1)

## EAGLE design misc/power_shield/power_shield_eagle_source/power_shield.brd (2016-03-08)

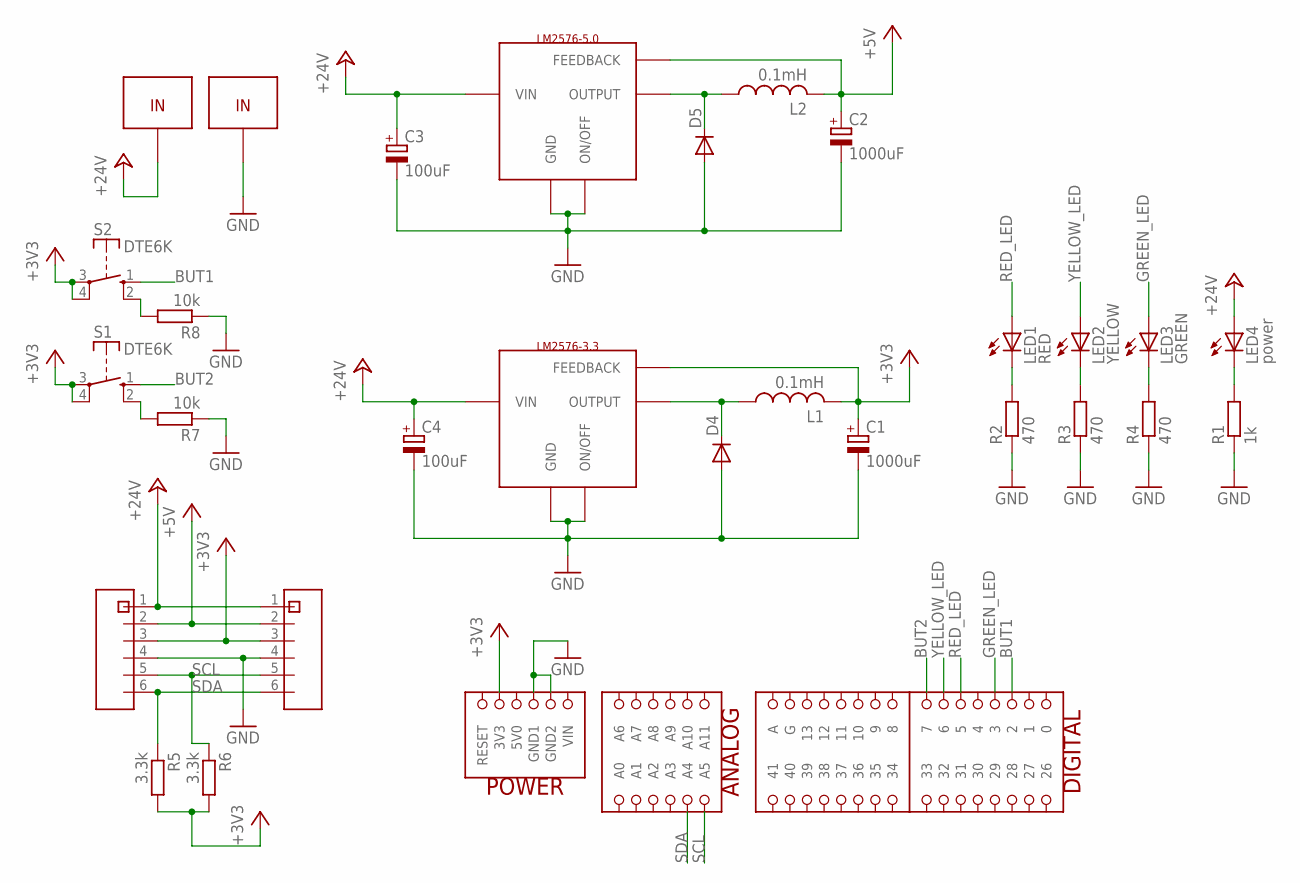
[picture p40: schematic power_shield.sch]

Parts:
C1, C2: 1000uF; 150CLZ-1010
C3, C4: 100uF; 150CLZ-1010
D4, D5: DIODE-DO214AA; DO214AA
L1, L2: 0.1mH; 6000-XXXX-RC
LED1: RED; CHIPLED_1206
LED2: YELLOW; CHIPLED_1206
LED3: GREEN; CHIPLED_1206
LED4: power; CHIPLED_1206
R1: 1k; R0603
R2, R3, R4: 470; R0603
R5, R6: 3.3k; R0603
R7, R8: 10k; R0603
S1, S2: DTE6K
U$1: UNO32_SHIELD
U$2: LM2576-5.0; TO-220-5
U$3: LM2576-3.3; TO-220-5
U$4, U$5: MOLEX_3.96MM_6P
U$6, U$7: LABBHYLSA

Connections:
+3V3: C1.+, L1.2, R5.2, R6.2, S1.3, S1.4, S2.3, S2.4, U$1.3V3, U$3.4 (FEEDBACK), U$4.3, U$5.3
+5V: C2.+, L2.2, U$2.4 (FEEDBACK), U$4.2, U$5.2
+24V: C3.+, C4.+, LED4.A, U$2.1 (VIN), U$3.1 (VIN), U$4.1, U$5.1, U$6.IN, U$6.IN2
BUT1: S2.1 (S), U$1.2
BUT2: S1.1 (S), U$1.7
GND: C1.-, C2.-, C3.-, C4.-, D4.A, D5.A, R1.1, R2.1, R3.1, R4.1, R7.1, R8.1, U$1.GND1, U$1.GND2, U$2.3 (GND), U$2.5 (ON/OFF), U$3.3 (GND), U$3.5 (ON/OFF), U$4.4, U$5.4, U$7.IN, U$7.IN2
GREEN_LED: LED3.A, U$1.3
unnamed: LED4.C, R1.2
unnamed: D5.C, L2.1, U$2.2 (OUTPUT)
unnamed: LED1.C, R2.2
unnamed: LED2.C, R3.2
unnamed: D4.C, L1.1, U$3.2 (OUTPUT)
unnamed: LED3.C, R4.2
unnamed: R7.2, S1.2 (S)
unnamed: R8.2, S2.2 (S)
RED_LED: LED1.A, U$1.5
SCL: R6.1, U$1.A5, U$4.5, U$5.5
SDA: R5.1, U$1.A4, U$4.6, U$5.6
YELLOW_LED: LED2.A, U$1.6

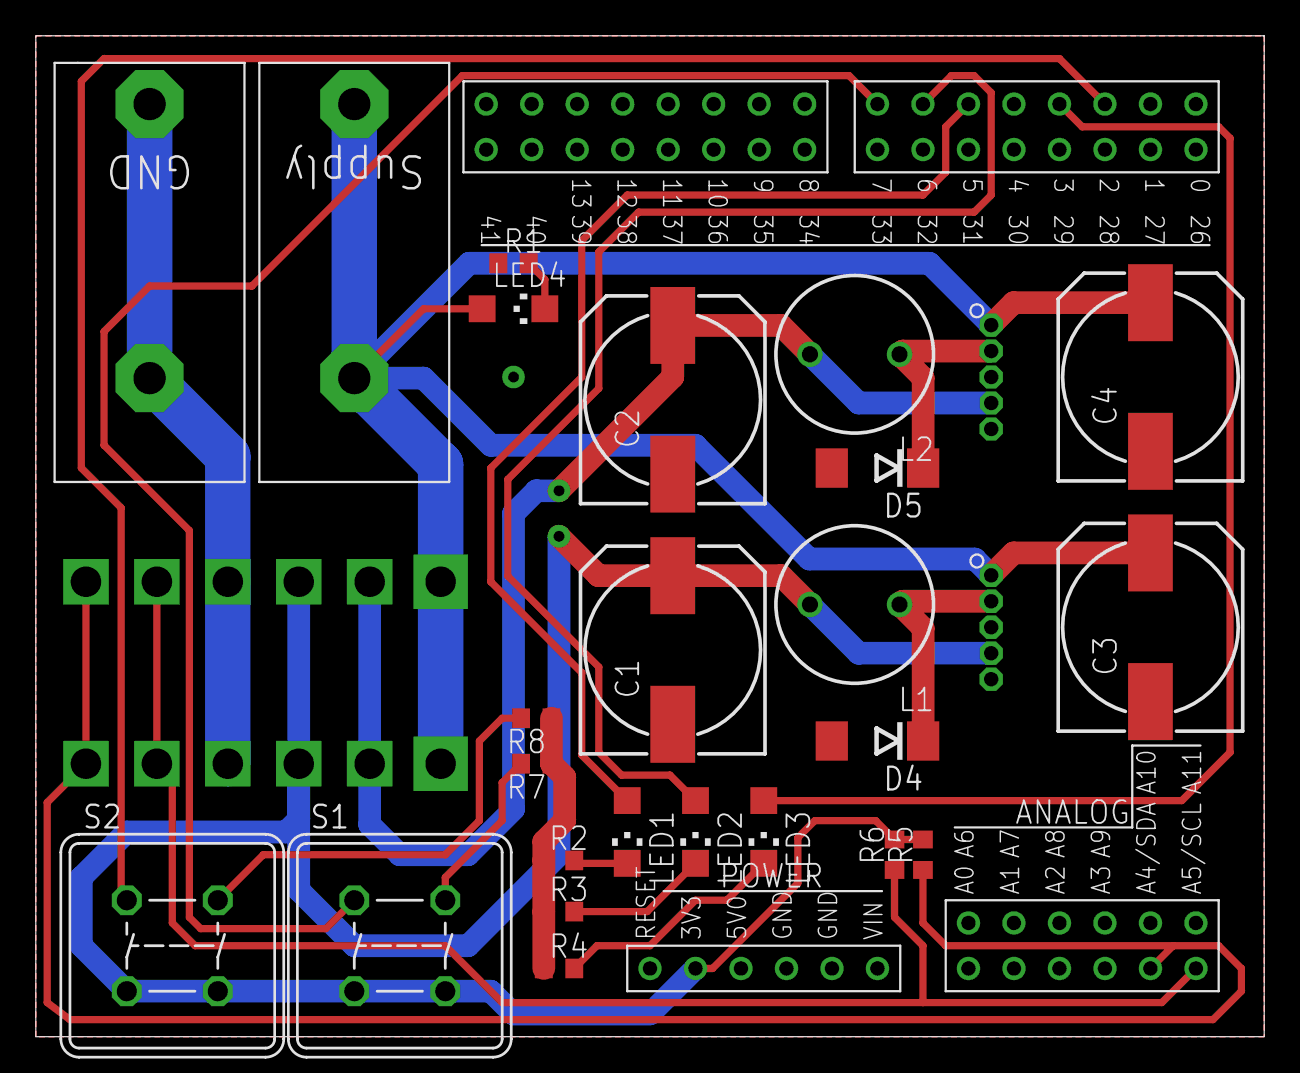
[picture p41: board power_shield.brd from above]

Board: 2 copper layers, 68.6 x 55.9 mm, 29 parts (0 on the bottom side), 19 nets.

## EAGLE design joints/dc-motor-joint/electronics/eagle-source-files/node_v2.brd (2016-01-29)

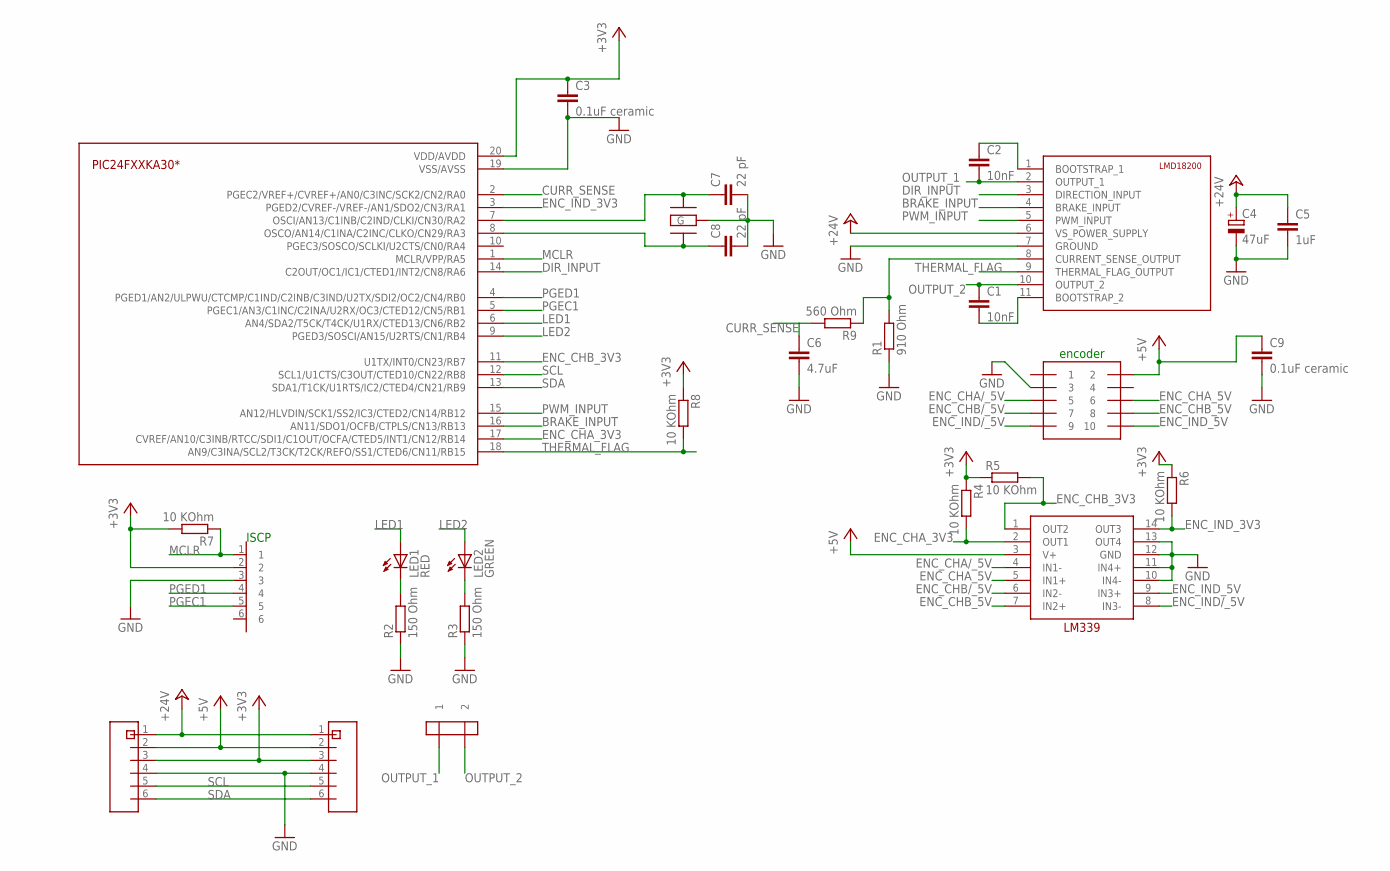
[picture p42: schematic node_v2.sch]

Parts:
C1, C2: 10nF; C0603
C3, C9: 0.1uF ceramic; C0805K
C4: 47uF; E5-10,5
C5: 1uF; C050-025X075
C6: 4.7uF; C0805K
C7, C8: 22 pF; C0603
LED1: RED; CHIPLED_1206
LED2: GREEN; CHIPLED_1206
R1: 910 Ohm; R0603
R2, R3: 150 Ohm; R0603
R4, R5, R6, R7, R8: 10 KOhm; R0603
R9: 560 Ohm; R0603
U$1: PIC24F32KA301; SSOP-20
U$2: LMD18200; TO-220-11
U$3, U$4: MOLEX_3.96MM_6P
U$5: DIN41651_10P
U$6: STIFTLIST_6X1P
U$7: CRYSTAL_ELFA; CRYSTAL_SMD
U$8: PCB_SKRUVPLINT_2P
U$9: LM339; SO14

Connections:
+3V3: C3.1, R4.1, R5.1, R6.1, R7.2, R8.1, U$1.20 (VDD/AVDD), U$3.3, U$4.3, U$6.2
+5V: C9.1, U$3.2, U$4.2, U$5.2, U$9.3 (V+)
+24V: C4.+, C5.1, U$2.6 (VS_POWER_SUPPLY), U$3.1, U$4.1
BRAKE_INPUT: U$1.16 (AN11/SDO1/OCFB/CTPLS/CN13/RB13), U$2.4 (BRAKE_INPUT)
CURR_SENSE: C6.1, R9.2, U$1.2 (PGEC2/VREF+/CVREF+/AN0/C3INC/SCK2/CN2/R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)
CURR_SENSE_OUTPUT: R1.2, R9.1, U$2.8 (CURRENT_SENSE_OUTPUT)
DIR_INPUT: U$1.14 (C2OUT/OC1/IC1/CTED1/INT2/CN8/RA6), U$2.3 (DIRECTION_INPUT)
ENC_CHA/_5V: U$5.5, U$9.4 (IN1-)
ENC_CHA_3V3: R4.2, U$1.17 (CVREF/AN10/C3INB/RTCC/SDI1/C1OUT/OCFA/C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), U$9.2 (OUT1)
ENC_CHA_5V: U$5.6, U$9.5 (IN1+)
ENC_CHB/_5V: U$5.7, U$9.6 (IN2-)
ENC_CHB_3V3: R5.2, U$1.11 (U1TX/INT0/CN23/RB7), U$9.1 (OUT2)
ENC_CHB_5V: U$5.8, U$9.7 (IN2+)
ENC_IND/_5V: U$5.9, U$9.8 (IN3-)
ENC_IND_3V3: R6.2, U$1.3 (PGED2/CVREF-/VREF-/AN1/SDO2/CN3/RA1), U$9.14 (OUT3)
ENC_IND_5V: U$5.10, U$9.9 (IN3+)
GND: C3.2, C4.-, C5.2, C6.2, C7.2, C8.2, C9.2, R1.1, R2.1, R3.1, U$1.19 (VSS/AVSS), U$2.7 (GROUND), U$3.4, U$4.4, U$5.3, U$6.3, U$7.2 (G), U$7.4 (G), U$9.10 (IN4-), U$9.11 (IN4+), U$9.12 (GND), U$9.13 (OUT4)
LED1: LED1.A, U$1.6 (AN4/SDA2/T5CK/T4CK/U1RX/CTED13/CN6/RB2)
LED2: LED2.A, U$1.9 (PGED3/SOSCI/AN15/U2RTS/CN1/RB4)
MCLR: R7.1, U$1.1 (MCLR/VPP/RA5), U$6.1
unnamed: C1.2, U$2.11 (BOOTSTRAP_2)
unnamed: LED1.C, R2.2
unnamed: LED2.C, R3.2
unnamed: C2.1, U$2.1 (BOOTSTRAP_1)
unnamed: C7.1, U$1.7 (OSCI/AN13/C1INB/C2IND/CLKI/CN30/RA2), U$7.3 (CRYSTAL_2)
unnamed: C8.1, U$1.8 (OSCO/AN14/C1INA/C2INC/CLKO/CN29/RA3), U$7.1 (CRYSTAL_1)
OUTPUT_1: C2.2, U$2.2 (OUTPUT_1), U$8.1
OUTPUT_2: C1.1, U$2.10 (OUTPUT_2), U$8.2
PGEC1: U$1.5 (PGEC1/AN3/C1INC/C2INA/U2RX/OC3/CTED12/C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), U$6.5
PGED1: U$1.4 (PGED1/AN2/ULPWU/CTCMP/C1IND/C2INB/C3IND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), U$6.4
PWM_INPUT: U$1.15 (AN12/HLVDIN/SCK1/SS2/IC3/CTED2/CN14/RB12), U$2.5 (PWM_INPUT)
SCL: U$1.12 (SCL1/U1CTS/C3OUT/CTED10/CN22/RB8), U$3.5, U$4.5
SDA: U$1.13 (SDA1/T1CK/U1RTS/IC2/CTED4/CN21/RB9), U$3.6, U$4.6
THERMAL_FLAG: R8.2, U$1.18 (AN9/C3INA/SCL2/T3CK/T2CK/REFO/SS1/CTED6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), U$2.9 (THERMAL_FLAG_OUTPUT)

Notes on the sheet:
encoder
ISCP

Board: 2 copper layers, 29 parts (1 on the bottom side), 34 nets, no tracks yet.

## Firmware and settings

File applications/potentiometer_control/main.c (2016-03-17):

/* 
 * File:   main.c
 * Author: Viktor Kozma
 *
 * Created on January 17, 2016, 3:19 PM
 *
 * Directly controls up to two motor nodes
 * by potentiometers.
 * 
 * Electrical connections (uC loc(uno32 pin)):
 * On board uno32 leds on PORTG6 and PORTF0
 * RED LED ON PORTD1(5)
 * YELLOW LED ON PORTD2(6)
 * BUTTON 1 on PORTD8(2)
 * BUTTON 2 on PORTD9(7)
 * POTENTIOMETER 1 on AN2(A0)
 * POTENTIOMETER 2 on AN4(A1)
 * 
 * To initiate control of the motors press BUTTON 1
 * and control the first motor with potentiometer 1 and 
 * control the second motor with potentiometer 2.
 * 
 * To change the id's of the controlled motors change the 
 * NODE1_ID and/or NODE2_ID definitions below.
 */
 
#define _SUPPRESS_PLIB_WARNING  // Removes spam
#define _DISABLE_OPENADC10_CONFIGPORT_WARNING

#include <plib.h>
#include <xc.h>
#include "../../api/pic32/modular_arms.h" //path to modular_arms.h

// Configs
#pragma config FPLLMUL = MUL_20, FPLLIDIV = DIV_2, FPLLODIV = DIV_1, FWDTEN = OFF
#pragma config POSCMOD = HS, FNOSC = PRIPLL, FPBDIV = DIV_1
#define SYS_FREQ (80000000L)

// Id's of the motors to be controlled
#define NODE1_ID 1
#define NODE2_ID 2

// Position or velociy feedback
//#define MODE_SPEED_FEEDBACK
//#define MODE_POSITION_FEEDBACK
#define MODE_DIRECT_VOLTAGE

// Clock reading functions used with the above config
#define GetSystemClock()           (SYS_FREQ)
#define GetPeripheralClock()       (SYS_FREQ/1)
#define GetInstructionClock()      (SYS_FREQ)

// ONBOARD LEDS OF THE UNO32
#define INIT_LEDS() (TRISGCLR = 1 << 6, TRISFCLR = 1)
#define LED4_ON() (PORTGSET = 1 << 6)
#define LED4_OFF() (PORTGCLR = 1 << 6)
#define LED4_SWAP() (PORTGINV = 1 << 6)
#define LED5_ON() (PORTFSET = 1)
#define LED5_OFF() (PORTFCLR = 1)
#define LED5_SWAP() (PORTFINV = 1)

// SHIELD LEDS
#define INIT_SHIELD_LEDS() (TRISDCLR = (1 << 1) | (1 << 2))
#define RED_LED_ON() (PORTDSET = 1 << 1)
#define RED_LED_OFF() (PORTDCLR = 1 << 1)
#define RED_LED_SWAP() (PORTDINV = 1 << 1)
#define YELLOW_LED_ON() (PORTDSET = 1 << 2)
#define YELLOW_LED_OFF() (PORTDCLR = 1 << 2)
#define YELLOW_LED_SWAP() (PORTDINV = 1 << 2)

// Shield Buttons
#define INIT_BUTS() (TRISDSET = 1 << 8 | 1 << 9)
#define GET_BUT1() (PORTDbits.RD8)
#define GET_BUT2() (PORTDbits.RD9)

// Pulse trigger for oscilloscope triggering
#define INIT_PULSE_TRIGGER() (TRISECLR = 1)
#define PULSE_TRIGGER() (LATESET = 1, LATECLR = 1)

#define A0 0
#define A1 1
unsigned int read_adc(unsigned char channel) {
    if (channel == A1)
        AD1CHS = ADC_CH0_NEG_SAMPLEA_NVREF | ADC_CH0_POS_SAMPLEA_AN4;
    else if (channel == A0)
        AD1CHS = ADC_CH0_NEG_SAMPLEA_NVREF | ADC_CH0_POS_SAMPLEA_AN2;
    else
        return 0;
    int i;
    for (i = 0; i < 10; i++); // small delay (may not be needed but w/e)
    AcquireADC10();
    for (i = 0; i < 100; i++); // Wait for sampling to complete
    ConvertADC10();
    while(!BusyADC10());
    return ReadADC10(0);
}

// Global vars
unsigned char buf[256]; // OUTPUT BUFFER FOR UART



int main(void) {
    // Configure the device for maximum performance but do not change the PBDIV
    // Given the options, this function will change the flash wait states and
    // enable prefetch cache but will not change the PBDIV. The PBDIV value
    // is already set via the pragma FPBDIV option above..
    SYSTEMConfig(SYS_FREQ, SYS_CFG_WAIT_STATES | SYS_CFG_PCACHE);

    // SETS UP UART, calculating the baud rates are done as follows:
    // BAUD = FPG / (16* (U1BRG + 1))  ==>
    // U1BRG = FPG / (16*BAUD) - 1
    // Where FPG = F_CPU / FPBDIV ( 80 MHz )
    // So 129 for 38400, 42 for 115200
    // found on computer at /dev/ttyUSB0
    OpenUART1(UART_EN,UART_TX_ENABLE | UART_RX_ENABLE,42);

    // SETUP TIMER 1 INTERUPPT!
    //Open Timer1, 256 Prescaler -> Fclock = 312500 Hz. With period = 6250 -> tick = 50 Hz
    OpenTimer1(T1_ON | T1_PS_1_256 | T1_SOURCE_INT, 6250);
    ConfigIntTimer1(T1_INT_ON | T1_INT_PRIOR_2);

    // configure and enable the ADC
    // A0 = AN2, A1 = AN4
    CloseADC10();    // ensure the ADC is off before setting the configuration
    AD1CHS = ADC_CH0_NEG_SAMPLEA_NVREF | ADC_CH0_POS_SAMPLEA_AN2; // configure to sample AN2
    mPORTBSetPinsAnalogIn(SKIP_SCAN_ALL);
    AD1CSSL = ~(ENABLE_AN2_ANA | ENABLE_AN4_ANA);
    AD1CON3 = ADC_CONV_CLK_PB | ADC_SAMPLE_TIME_15 | ADC_CONV_CLK_16Tcy;
    AD1CON2 = ADC_VREF_AVDD_AVSS | ADC_OFFSET_CAL_DISABLE | ADC_SCAN_OFF | \
              ADC_ALT_BUF_OFF | ADC_ALT_INPUT_OFF;
    AD1CON1 = ADC_MODULE_ON | ADC_FORMAT_INTG | ADC_CLK_MANUAL | ADC_AUTO_SAMPLING_OFF;
    EnableADC10(); // Enable the ADC

    // Button and LEDS
    INIT_LEDS();
    LED4_OFF(); LED5_OFF();
    INIT_SHIELD_LEDS();
    RED_LED_OFF(); YELLOW_LED_OFF();
    INIT_PULSE_TRIGGER(); 
    INIT_BUTS();


    // SAYS HELLO
    putsUART1("HELLO\n\r");
    
    // INIT the arm
    init_arm(GetPeripheralClock());

    // Enables interrupts
    INTEnableSystemMultiVectoredInt();
    
    while(1){
        // Works only with interrupts
    }
    return (EXIT_SUCCESS);
}

// Timer 1 interuppt routine, 50 Hz
void __ISR(_TIMER_1_VECTOR, IPL2AUTO) _Timer1Handler(void) {
    static UINT32 cnt = 0; // Incremented variables used for timing

    // Motor status variables
    static UINT8 motor1_status = MOTOR_STATUS_ENCODER_CALIBRATION_NEEDED;
    static UINT8 motor2_status = MOTOR_STATUS_ENCODER_CALIBRATION_NEEDED;
    static UINT8 motor1_i2c_status = 1, motor2_i2c_status = 1;

    // Check if button 1 is pressed, if enable/disable motor 1
    static UINT8 but1_pressed = 0;
    static UINT32 prev_but1_cnt = 0;
    if (GET_BUT1() && !but1_pressed && (cnt-prev_but1_cnt > 5) ) {
        // Init/exit motor 1
        if (motor1_i2c_status == I2C_STATUS_SUCCESFUL) {
            if( motor1_status != MOTOR_STATUS_ENCODER_CALIBRATION_NEEDED) {
                set_calibration_status_unknown(NODE1_ID);
                putsUART1("Motor 1 disabled\n\r");
            } else {
                calibrate_encoder_zero(NODE1_ID);
                putsUART1("Motor 1 enabled\n\r");
            }
        } else {
            sprintf(buf,"Motor 1 with id %d not found on the bus\n\r",NODE1_ID);
            putsUART1(buf);
        }
        // Debouncing and making sure the button only is pressed once
        // so holding it down doesn't call this function repeatedly
        prev_but1_cnt = cnt;
        but1_pressed = 1;
    } else if (!GET_BUT1() && but1_pressed && (cnt-prev_but1_cnt > 5)) {
        but1_pressed = 0;
        prev_but1_cnt = cnt;
    }
    // Check if button 2 is pressed, if enable/disable motor 2
    static UINT8 but2_pressed = 0;
    static UINT32 prev_but2_cnt = 0;
    if (GET_BUT2() && !but2_pressed && (cnt-prev_but2_cnt > 5) ) {
        // Init/exit motor 1
        if (motor2_i2c_status == I2C_STATUS_SUCCESFUL) {
            if( motor2_status != MOTOR_STATUS_ENCODER_CALIBRATION_NEEDED) {
                set_calibration_status_unknown(NODE2_ID);
                putsUART1("Motor 2 disabled\n\r");
            } else {
                calibrate_encoder_zero(NODE2_ID);
                putsUART1("Motor 2 enabled\n\r");
            }
        } else {
            sprintf(buf,"Motor 2 with id %d not found on the bus\n\r",NODE2_ID);
            putsUART1(buf);
        }
        // Debouncing and making sure the button only is pressed once
        // so holding it down doesn't call this function repeatedly
        prev_but2_cnt = cnt;
        but2_pressed = 1;
    } else if (!GET_BUT2() && but2_pressed && (cnt-prev_but2_cnt > 5)) {
        but2_pressed = 0;
        prev_but2_cnt = cnt;
    }


    // Read motor status
    LED5_ON();
    motor1_i2c_status = get_status(NODE1_ID,&motor1_status);
    motor2_i2c_status = get_status(NODE2_ID,&motor2_status);
    LED5_OFF();

    // Send references to motors if they're enabled
    float send_value;
    if (motor1_i2c_status == I2C_STATUS_SUCCESFUL && motor1_status != MOTOR_STATUS_ENCODER_CALIBRATION_NEEDED) {
        LED5_ON();
#if defined(MODE_SPEED_FEEDBACK)
        send_value = (((float)read_adc(A0))-512)*6.2831/512; // +- 360 deg/s
        motor1_i2c_status = set_angular_velocity(NODE1_ID,send_value);
#elif defined(MODE_DIRECT_VOLTAGE)
        send_value = (((float)read_adc(A0))-512)*24/512; // +- 24V
        motor1_i2c_status = set_voltage(NODE1_ID,send_value);
#else
        send_value = (((float)read_adc(A0))-512)*1.5708/512; // +- 90 degrees
        motor1_i2c_status = set_angle(NODE1_ID,send_value);
#endif
        LED5_OFF();
        RED_LED_ON();
    } else RED_LED_OFF();
    if (motor2_i2c_status == I2C_STATUS_SUCCESFUL && motor2_status != MOTOR_STATUS_ENCODER_CALIBRATION_NEEDED) {
        LED5_ON();
#if defined(MODE_SPEED_FEEDBACK)
        send_value = (((float)read_adc(A1))-512)*6.2831/512; // +- 360 deg/s
        motor2_i2c_status = set_angular_velocity(NODE2_ID,send_value);
#elif defined(MODE_DIRECT_VOLTAGE)
        send_value = (((float)read_adc(A1))-512)*24/512; // +- 24V
        motor2_i2c_status = set_voltage(NODE2_ID,send_value);
#else
        send_value = (((float)read_adc(A1))-512)*1.5708/512; // +- 90 degrees
        motor2_i2c_status = set_angle(NODE2_ID,send_value);
#endif
        LED5_OFF();
        YELLOW_LED_ON();
    } else YELLOW_LED_OFF();

    // Blink one on board led every 2 sec for visual feedback
    if (cnt % 100 == 0) {
        LED4_SWAP();
    }
    cnt++;
    mT1ClearIntFlag(); // clear interrupt flag
}

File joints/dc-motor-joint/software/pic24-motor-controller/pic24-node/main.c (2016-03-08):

/*
 * File:   main.c
 * Author: Viktor Kozma
 *
 * This program controls a motor node for a
 * modular robotic arm. It includes encoder
 * reading, motor control and communication
 * with a master controller through I2C.
 *
 * Important!
 * This code requires specific data to be
 * programmed into the microcontroller internal
 * eeprom memory.
 *
 * In addition, to accomodate for this fact the
 * programmer configuration must be set to
 * preserve the internal eeprom. This is done
 * in MPLABX for the PICKIT3 by:
 * Run -> Set Project Configuration -> Customize ->
 * -> PICKIT3 -> Conserve EEPROM Memory
 *
 *
 * Created on April 28, 2015
 */

//#include <PIC24F_plib.h>
#include <xc.h>

// Libraries
#include "main_init_functions.h"
#include "LMD18200_drivers.h"
#include "pic24_i2c_slave.h"
#include "eeprom_storage.h"
#include "control_tuner.h"


// START OF PROGRAM ------------------------------------------------------------
// Motor id
unsigned char motor_id = 0;

// Status
system_status_struct systemStatus = {
    .enc_calib = ENCODER_CALIBRATION_NEEDED,
    .control_prog_status = CONTROL_PROG_STATUS_NOTHING,
    .new_control_available = NO_NEW_CONTROLLER_AVAILABLE,
    .control_mode = CONTROL_MODE_DISABLED
};

// controller variables passed between
volatile float pos_ref = 0, vel_ref = 0, drive_voltage = 0, amp_ref = 0;
control_params_struct posControlParams, velControlParams;
motor_params_struct motorData;

#ifdef LED1_MODE_I2C
volatile int led1_timer_count = 0;
#endif

int main(void) {

    init_oscillator();

    INIT_LEDS();
    LED1_OFF();
    LED2_OFF();

    // Read from EEPROM, this is done first before anything else is
    // initiated in order to remove chances of data corruption
    if (!EepVerifyTest()) eepromErrorLoop();
    motor_id = EepReadNodeID();
    EepReadMotorParams(&motorData);
    EepReadPosControlParams(&posControlParams);
    EepReadVelControlParams(&velControlParams);
    if (velControlParams.cMode != CMODE_SPEED_CONTROL || posControlParams.cMode != CMODE_POSITION_CONTROL || motor_id > 16)
        eepromErrorLoop();

    Nop(); // Breakpoints for debugging
    Nop();

    // Initiate all the functions!
    init_encoders();
    init_timers(DEFAULT_FS);
    init_motor();
    init_i2c(motor_id);

    MOTOR_DISABLE();

    while(1) {
        // Do nothing, only works with interrupts
//        MOTOR_ENABLE_SWAP(); // Motor pin 5
//        int i;
//        for(i = 0; i < 10000; i++);
    }

    return 0;
}

// Prototypes, implementation at bottom
void control_loop(control_params_struct*,float,unsigned char);
void voltage_drive(float,unsigned char);
void set_current(float,unsigned char);

// Timer interrupt for sampling
void _ISR _T1Interrupt(void) {
    if(systemStatus.enc_calib == ENCODER_IS_CALIBRATED) LED2_ON();

    static unsigned int blink_count = 0;   // Count used for blinking the enc_needed thing
    static unsigned char reset_control_loop = 0; // If 1 the control loop will reset
    static unsigned char prev_control_mode = CONTROL_MODE_DISABLED;
    static unsigned int Fs = DEFAULT_FS;

    // Update eventual stored motor speed
    update_motor_speed();

    // If new control parameters is found, update
    if (systemStatus.new_control_available != NO_NEW_CONTROLLER_AVAILABLE) {
        if (systemStatus.new_control_available == NEW_CONTROLLER_AVAILABLE) {
            if (newControlParams.cMode == CMODE_POSITION_CONTROL)
                posControlParams = newControlParams;
            else if (newControlParams.cMode == CMODE_SPEED_CONTROL)
                velControlParams = newControlParams;
        } else if (systemStatus.new_control_available == NEW_CONTROLLER_DEFAULT) {
            EepReadPosControlParams(&posControlParams);
            EepReadVelControlParams(&velControlParams);
        }        
        systemStatus.new_control_available = NO_NEW_CONTROLLER_AVAILABLE;
        prev_control_mode = CONTROL_MODE_NEVER; // Force update of sampling rate
    }

    // Sets the sampling rate and resets parameters if the control mode is changed
    if (systemStatus.control_mode != prev_control_mode) {
        if (systemStatus.control_mode == CONTROL_MODE_POSITION_FEEDBACK)
            Fs = posControlParams.Fs;
        else if (systemStatus.control_mode == CONTROL_MODE_SPEED_FEEDBACK)
            Fs = velControlParams.Fs;
        else
            Fs = DEFAULT_FS;
        reset_control_loop = 1;
        blink_count = 0;
#ifdef LED1_MODE_I2C
        led1_timer_count = -1;
        LED1_OFF();
#endif
        set_timer1_period(Fs);
        TMR1 = 0;
        prev_control_mode = systemStatus.control_mode;
    }
    

    // Does stuff depending on what it wants to do
    if (systemStatus.control_mode == CONTROL_MODE_DISABLED || systemStatus.enc_calib == ENCODER_CALIBRATION_NEEDED) {
        MOTOR_DISABLE(); MOTOR_BRAKE_ON();
        set_motor_speed(0.0);
    } else if (systemStatus.control_mode == CONTROL_MODE_POSITION_FEEDBACK) {
        MOTOR_ENABLE(); MOTOR_BRAKE_OFF();
        control_loop(&posControlParams,pos_ref,reset_control_loop); // Main pos control loop
        reset_control_loop = 0;
    } else if (systemStatus.control_mode == CONTROL_MODE_SPEED_FEEDBACK) {
        MOTOR_ENABLE(); MOTOR_BRAKE_OFF();
        control_loop(&velControlParams,vel_ref,reset_control_loop); // Main speed control loop
        reset_control_loop = 0;
    } else if (systemStatus.control_mode == CONTROL_MODE_VOLTAGE) {
        MOTOR_ENABLE(); MOTOR_BRAKE_OFF();
        voltage_drive(drive_voltage,reset_control_loop);
        reset_control_loop = 0;
    } else if (systemStatus.control_mode == CONTROL_MODE_DIRECT_VOLTAGE) {
        MOTOR_ENABLE(); MOTOR_BRAKE_OFF();
        set_motor_speed(drive_voltage);
    } else if (systemStatus.control_mode == CONTROL_MODE_CURRENT) {
        MOTOR_ENABLE(); MOTOR_BRAKE_OFF();
        set_current(amp_ref,reset_control_loop);
        reset_control_loop = 0;
    } else {
        // Just in case
        systemStatus.control_mode = CONTROL_MODE_DISABLED;
    }

    // LED CONTROL
    if (systemStatus.enc_calib == ENCODER_CALIBRATION_NEEDED) {
        // When encoder calibration is needed, 1Hz 20% signal
        float blink_sec = ((float) blink_count)/((float) Fs);
        if ( (blink_sec > 0.8) && (blink_sec < 2.5) ) {
            LED2_ON();
            blink_count = 3*Fs;
        } else if (blink_sec > 3.2) {
            LED2_OFF();
            blink_count = 0;
        }
        blink_count += 1;
    } else {
        // When running, on all the time if thermal flag is on
        // else switch it off, this allows the user to see
        // CPU utilization
        if (!GET_THERMAL_FLAG())
            LED2_ON();
        else
            LED2_OFF();
    }
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

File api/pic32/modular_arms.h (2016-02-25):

/* 
 * File:   modular_arms.h
 * Author: Viktor Kozma
 *
 * Communicates with motor nodes in the distributed
 * system.
 *
 * Also includes functions to write and read from the i2c bus
 *
 * All the message functions will return a status variable
 * of the transmission. This variable can take the following
 * values:
 *  0 - Success
 *  1 - NACK recieved during address transmission
 *  2 - NACK recieved during data transmission
 *  3 - Collision occured during start
 *  4 - Failed to transmit
 *  5 - I2C receiver overflow
 *
 * Created on May 19, 2015
 */

#ifndef MODULAR_ARMS_H
#define	MODULAR_ARMS_H

#include "pic32_i2c.h"


// This will make this print debug messages to the computer
//#define PRINT_DEBUG_MESSAGES

// Definitions of the motor node chips
#define MOTOR_CONTROL_CODE 0b0010
#define ID_TO_ADDRESS(id) ((MOTOR_CONTROL_CODE << 3) | id)

// I2C clock frequency used by the system
#define I2C_CLOCK_FREQ             100000

/*
* Identification codes for the I2C protocol
*/
#define I2C_DISABLE_MOTOR                   0
#define I2C_SET_POSITION_REFERENCE          1
#define I2C_SET_SPEED_REFERENCE             2
#define I2C_SET_DRIVE_VOLTAGE               3
#define I2C_SET_DIRECT_DRIVE_VOLTAGE        4
#define I2C_SET_TORQUE                      5

#define I2C_SET_TRAJECTORY                  7

#define I2C_ENABLE_BRAKE                    14
#define I2C_DISABLE_BRAKE                   15

#define I2C_CALIBRATE_ENCODER_ZERO          16
#define I2C_CALIBRATE_ENCODER_PROVIDED      17
#define I2C_SET_CALIBRATE_STATUS_UNKNOWN    31

#define I2C_PROGRAM_NEW_CONTROL_PARAMS      32
#define I2C_USE_DEFAULT_CONTROL_PARAMS      33
#define I2C_TUNE_CONTROL_PARAMS             34

#define I2C_READMODE_ANGLE                  128
#define I2C_READMODE_POS_REFERENCE          129
#define I2C_READMODE_VEL_REFERENCE          130
#define I2C_READMODE_STATUS                 131
#define I2C_READMODE_CONTROL_PROG_STATUS    132
#define I2C_READMODE_VOLTAGE                133
#define I2C_READMODE_CURRENT                134
#define I2C_READMODE_WHO_AM_I               136
#define I2C_READMODE_POS_CONTROL_PARAMS     138
#define I2C_READMODE_VEL_CONTROL_PARAMS     139

#define I2C_TURN_ON_LED                     252
#define I2C_TURN_OFF_LED                    253
#define I2C_SWAP_LED                        254

// Motor status
#define MOTOR_STATUS_ENABLED                    1
#define MOTOR_STATUS_DISABLED                   2
#define MOTOR_STATUS_ENCODER_CALIBRATION_NEEDED 3

// Control programming status
#define MOTOR_CONTROL_PROGRAMMING_STATUS_NOTHING    1
#define MOTOR_CONTROL_PROGRAMMING_STATUS_SUCCESS    2
#define MOTOR_CONTROL_PROGRAMMING_STATUS_FAILED     3

// Some goto parameters for tuning the controller
// Possible controller types
#define TUNING_PD_POSITION_CONTROLLER   0
#define TUNING_PID_POSITION_CONTROLLER  1
#define TUNING_PI_SPEED_CONTROLLER      2
// Inertias (check plausible inertias)
#define TUNING_LOW_INERTIA          0.05
#define TUNING_MEDIUM_INERTIA       0.2
#define TUNING_HIGH_INERTIA         0.5
#define TUNING_HUGE_INERTIA         1.0
#define TUNING_HUMONGOUS_INERTIA    1.5
// Poles
#define TUNING_POSITION_POLE_FAST   -12.0
#define TUNING_POSITION_POLE_MEDIUM -9.0
#define TUNING_POSITION_POLE_SLOW   -6.0
#define TUNING_SPEED_POLE_FAST      -60.0
#define TUNING_SPEED_POLE_MEDIUM    -40.0
#define TUNING_SPEED_POLE_SLOW      -20.0



// Control parameter struct (TODO: fix)
#define CMODE_POSITION_CONTROL 0
#define CMODE_SPEED_CONTROL 1
typedef struct tag_control_params_struct {
    unsigned char cMode;    // 0 = position control, 1 = speed control
    unsigned int Fs;        // Sampling frequency
    unsigned char nd;       // number of feedback numerator constants
    float d[4];             // Feedback numerator constants
    unsigned char nc;       // number of feedforward numerator constants
    float c[4];             // Feedforward numerator constants
    unsigned char nf;       // number of feedback/forward denominator constants
    float f[4];             // Feedback/forward denominator constants
    float I;                // Optional integrator for both feedback/forward
} control_params_struct;



#ifdef PRINT_DEBUG_MESSAGES
// externally defined output buffer for printing debug messages
extern unsigned char buf[256];
#endif

/*
 * Functions for communicating with the motor node
 */

/*
 * Initiates the I2C module on the system to communicate with the
 *
 * input:
 *  current system peripheral clock
 *
 * output:
 *  none
 *
 * example code:
 *  init_arm(SYS_FREQ/1); // Depends on you current peripheral clock
 */
void init_arm(UINT32 system_peripheral_clock);

/*
 * Reads a float from the node
 *
 * input:
 *  id of the motor
 *  id of what parameter you want to read
 *  pointer to where to store the result
 *
 * output:
 *  i2c status of the message
 *
 * example code: 
 *  // Read the angle of the motor
 *  float motor_angle;
 *  UINT8 i2c_status = node_read_float(1,I2C_READMODE_ANGLE,&motor_angle);
 *  if (i2c_status == I2C_STATUS_SUCCESFUL) {
 *      // read succesful, do something with motor_angle
 *  }
 *
 */
UINT8 node_read_float(UINT8 address, UINT8 read_id, float* output);

/*
 * Reads a single byte from the node
 *
 * input:
 *  id of the motor
 *  id of what parameter you want to read
 *  pointer to where to store the result
 *
 * output:
 *  i2c status of the message
 *
 * example code:
 *  // Read the status of the motor
 *  UINT8 i2c_status, node_status;
 *  i2c_status = node_read_float(1,I2C_READMODE_STATUS,&node_status);
 *  if (i2c_status == I2C_STATUS_SUCCESFUL) {
 *      // read succesful, do something with node_status
 *  }
 * 
 */
UINT8 node_read_byte(UINT8 address, UINT8 read_id, UINT8* output);

/*
 * Writes a single command to the motor node.
 *
 * input:
 *  id of the motor
 *  the command you want to send
 *
 * output:
 *  i2c status of the message
 *
 * example code:
 *  // Send that you want to calibrate the encoder
 *  UINT8 i2c_status = node_write_command(1,I2C_CALIBRATE_ENCODER_ZERO);
 *  if (i2c_status != I2C_STATUS_SUCCESFUL) {
 *      // Transmission failed, take proper action
 *  }
 */
UINT8 node_write_command(UINT8 address, UINT8 command);

/*
 * Writes a command and a byte of data to the motor node.
 * Not used for any command to the motors but could be used for
 * communicating with other external devices
 *
 * input:
 *  id of the motor
 *  the command you want to send
 *  the data you want to write (byte)
 *
 * output:
 *  i2c status of the message
 */
UINT8 node_write_byte(UINT8 address, UINT8 command, UINT8 write_data);
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

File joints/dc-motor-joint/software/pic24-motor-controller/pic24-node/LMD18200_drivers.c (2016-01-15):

#ifndef LMD18200_DRIVERS
#define	LMD18200_DRIVERS

#include "LMD18200_drivers.h"
//#include <PIC24F_plib.h>
#include <xc.h>

void init_motor(void) {
    // Enable pin (PWM input on the LMD18200)
    TRISBbits.TRISB12 = 0;
    MOTOR_DISABLE();

    // Brake pin
    TRISBbits.TRISB13 = 0;
    MOTOR_BRAKE_OFF();

    // THERMAL_FLAG pin
    TRISBbits.TRISB15 = 1;
    ANSBbits.ANSB15 = 0;

    // Configures PWM output (direction pin on the LMD18200)
    // 50% PWM still, 0% full left, 100% full right

    TRISAbits.TRISA6 = 0; // Output

    // Timer 2 for PWM
    T2CONbits.T32 = 0;      // pwm can only operate in 16-bit mode
    T2CONbits.TCKPS = 0;    // prescaler: 0 = 1:1, 1 = 1:8, 2 = 1:64, 3 = 1:256
    T2CONbits.TCS = 0;      // internal clock source
    T2CONbits.TON = 1;      // Enable
#ifdef USE_CENTER_ALIGNED_PWM
    // For center aligned the period goes into the timer period register
    PR2 = MOTOR_PWM_PERIOD;

    // OC1-pin
    OC1RS = (unsigned int)(((float)MOTOR_PWM_PERIOD)*0.75);    // Go low value
    OC1R =  (unsigned int)(((float)MOTOR_PWM_PERIOD)*0.25);  // Go high value
    OC1CON2bits.SYNCSEL = 0b01100;
    OC1CON2bits.OCTRIG = 0;
    OC1CON2bits.DCB = DCB_OFFSET;
    OC1CON1bits.OCTSEL = 0;     // Timer2 input
    OC1CON1bits.OCM = 0b111;    // Center-aligned PWM mode
#else
#ifndef USE_EDGE_ALIGNED_PWM
#warning PWM mode not defined, assuming edge aligned
#endif
    PR2 = 0xFFFF;

    // OC1-pin
    OC1RS = MOTOR_PWM_PERIOD;    // Period
    OC1R =  ((unsigned int) ((float)MOTOR_PWM_PERIOD)/2);  // Duty cycle
    OC1CON2bits.SYNCSEL = 0x1F;
    OC1CON2bits.OCTRIG = 0;
    OC1CON2bits.DCB = 0;
    OC1CON1bits.OCTSEL = 0;     // Timer2 input
    OC1CON1bits.OCM = 0b110;    // Edge-aligned PWM mode
#endif


    // Configures ADC for current sensing
    TRISAbits.TRISA0 = 1;   // Input
    ANSAbits.ANSA0 = 1;     // Analog signal
    AD1CON2bits.PVCFG = 0;  // AVdd (Vdd) positive reference voltage
    AD1CON2bits.NVCFG = 0;  // AVss (Vss) negative reference voltage
    AD1CON1bits.MODE12 = 1; // 12 bit resolution
    AD1CON1bits.FORM = 0;   // Unsigned integer
    AD1CON1bits.SSRC = 0;   // Manual sampling
    AD1CON1bits.ASAM = 0;   // Don't autosample
    AD1CON3bits.ADRC = 0;   // Internal clock as clock source

    AD1CHSbits.CH0SA = 0;   // AN0 positive
    AD1CHSbits.CH0NA = 0;   // AVss negative

    AD1CON1bits.ADON = 1;   // Turns on the module
    AD1CON1bits.SAMP = 1;   // Starts a sampling

}

void ADC_sample(void) {
    AD1CON1bits.SAMP = 0;   // Starts conversion
}

unsigned int ADC_read(void) {
    while(AD1CON1bits.DONE == 0);   // Waits for it to finish
    AD1CON1bits.SAMP = 1;   // Starts a new sampling
    return ADC1BUF0;
}

float read_current(void) {
    ADC_sample();
    return ((((float)ADC_read()) * 3.3 / 4095.0)/CURRENT_SENSE_RESISTOR ) / (0.000377);
}

float read_voltage(void) {
#ifdef USE_DCB_BITS
    float dc = (((float) (OC1RS - OC1R)) + (((float) OC1CON2bits.DCB) - DCB_OFFSET )/4.0) / ((float)MOTOR_PWM_PERIOD + 1.0);
#else
    float dc = ((float) (OC1RS - OC1R)) / (MOTOR_PWM_PERIOD + 1.0);
#endif
    return (dc - 0.5)*SUPPLY_VOLTAGE/0.5;
}

void set_motor_speed(float spd) {
    if (spd < -LIMIT_VOLTAGE) spd = -LIMIT_VOLTAGE;
    if (spd > LIMIT_VOLTAGE) spd = LIMIT_VOLTAGE;

#ifdef USE_CENTER_ALIGNED_PWM
    float dc = 0.5*spd/SUPPLY_VOLTAGE + 0.5;
    unsigned int diff = (unsigned int) (4.0 * dc * ((float) MOTOR_PWM_PERIOD + 1.0) + 0.5);
#ifdef USE_DCB_BITS
    unsigned char dcb_temp = (diff & 0b11) + DCB_OFFSET;
    OC1CON2bits.DCB = dcb_temp & 0b11;
    diff = diff + (dcb_temp & 0xfc);
#endif
    unsigned int offset = ((MOTOR_PWM_PERIOD + 1) - (diff >> 2)) / 2;
    if ( diff == 0 ) {
        OC1RS = 0;
        OC1R = (MOTOR_PWM_PERIOD + 1);
    } else {
        OC1RS = offset + (diff >> 2);
        OC1R =  offset;
    }

#else
    OC1R = ((unsigned int) ( 0.5*((float) MOTOR_PWM_PERIOD)*spd/SUPPLY_VOLTAGE + 0.5*((float)MOTOR_PWM_PERIOD) ) ) ;
#endif
}

void set_delayed_motor_speed(float spd, unsigned char task) {
#ifdef USE_CENTER_ALIGNED_PWM
    static unsigned int OC1R_NEW = (unsigned int)(((float)MOTOR_PWM_PERIOD)*0.25);
    static unsigned int OC1RS_NEW = (unsigned int)(((float)MOTOR_PWM_PERIOD)*0.75);
    static unsigned char DCB_NEW = 0;
#else
    static unsigned int OC1R_NEW = ((unsigned int) ((float)MOTOR_PWM_PERIOD)/2);
#endif
    static unsigned char new_stuff_available = 0;
    static float input_voltage = 0.0;

    if (task == 0) {
        // Calculate all the floating point values
        if (spd < -LIMIT_VOLTAGE) spd = -LIMIT_VOLTAGE;
        if (spd > LIMIT_VOLTAGE) spd = LIMIT_VOLTAGE;
        
#ifdef USE_CENTER_ALIGNED_PWM
        float dc = 0.5*spd/SUPPLY_VOLTAGE + 0.5;
        unsigned int diff = (unsigned int) (4.0 * dc * ((float) MOTOR_PWM_PERIOD + 1.0) + 0.5);
#ifdef USE_DCB_BITS
        unsigned char dcb_temp = (diff & 0b11) + DCB_OFFSET;
        DCB_NEW = dcb_temp & 0b11;
        diff = diff + (dcb_temp & 0xfc);
#endif
        unsigned int offset = ((MOTOR_PWM_PERIOD + 1) - (diff >> 2)) / 2;
        if ( diff == 0 ) {
            OC1RS_NEW = 0;
            OC1R_NEW = (MOTOR_PWM_PERIOD + 1);
        } else {
            OC1RS_NEW = offset + (diff >> 2);
            OC1R_NEW =  offset;
        }
#else
        OC1R_NEW = ((unsigned int) ( 0.5*((float) MOTOR_PWM_PERIOD)*spd/SUPPLY_VOLTAGE + 0.5*((float)MOTOR_PWM_PERIOD) ) ) ;
#endif
        new_stuff_available = 1;
        input_voltage = spd;
    } else if (new_stuff_available) {
#ifdef USE_CENTER_ALIGNED_PWM
        OC1RS = OC1RS_NEW;
        OC1R = OC1R_NEW;
#ifdef USE_DCB_BITS
        OC1CON2bits.DCB = DCB_NEW;
#endif
        new_stuff_available = 0;
#else
        OC1R = OC1R_NEW;
#endif
//#ifdef MINIMUM_VOLTAGE
//        if (input_voltage < MINIMUM_VOLTAGE && input_voltage > -MINIMUM_VOLTAGE)
//            MOTOR_DISABLE();
//        else
//            MOTOR_ENABLE();
//#endif
    }

}

void set_duty_cycle(float dc) {
    if (dc > 100.0) dc = 100;
    if (dc < 0.0) dc = 0;

#ifdef USE_CENTER_ALIGNED_PWM
    unsigned int diff = (unsigned int) (4.0 * dc/100.0 * ((float) MOTOR_PWM_PERIOD + 1.0) + 0.5);
#ifdef USE_DCB_BITS
    unsigned char dcb_temp = (diff & 0b11) + DCB_OFFSET;
    OC1CON2bits.DCB = dcb_temp & 0b11;
    diff = diff + (dcb_temp & 0xfc);
#endif
    unsigned int offset = ((MOTOR_PWM_PERIOD + 1) - (diff >> 2)) / 2;
    if ( diff == 0 ) {
        OC1RS = 0;
        OC1R = (MOTOR_PWM_PERIOD + 1);
    } else {
        OC1RS = offset + (diff >> 2);
        OC1R =  offset;
    }
#else
    OC1R = (unsigned int) ( dc/100.0 * ((float) MOTOR_PWM_PERIOD) );
#endif
}


#ifdef USE_CENTER_ALIGNED_PWM
void set_PWM_period(unsigned int rs, unsigned int r, unsigned int dcb) {
    OC1RS = rs;
    OC1R = r;
    OC1CON2bits.DCB = dcb;
}
#else
void set_PWM_period(unsigned int p) {
    if (p > MOTOR_PWM_PERIOD) p = MOTOR_PWM_PERIOD;
    OC1R = p;
}
#endif
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

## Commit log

2016-01-15 Added pen end effector files
    [arduino_holder.stl, pen_base.stl, pen_holder_10mm8.stl]
2016-01-15 Added joint software and electronics
    [node.brd, node.sch, power_shield.brd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]
2016-01-29 Added pendulum applications
    [node_v2.brd, node_v2.sch]
2016-02-08 added hardware
    [22mm Joint P1.stl, 22mm Joint P2.stl, 22mm Joint P3.stl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]
2016-02-08 added bill of material to hardware
2016-02-23 Added assembly instructions for the dc-motor joint
2016-02-25 Some new hardware and assembly instructions
    [22mm Joint P1.stl, 22mm bottom_conn.stl, 22mm top_conn.stl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]
2016-03-08 Improved some joint code
2016-03-08 Added picture of the schematics of the power shield.
2016-03-08 Added the pendulum joint
    [Asm1.cfg, inner-left.stl, outer-connect.stl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]
2016-03-08 Added pendulum joint README.
2016-03-08 Seperated the electronics
    [power_shield.brd, power_shield.sch]
2016-03-08 Tests. Current version of the pendulum is not working.
    [main.c, mpu9150.c]
2016-03-17 New controller for small motor in pendulum
2016-03-17 Fixed some tuning code in pendulum
    [main.c]
2016-03-18 Fixed and added some stuff for pendulum
    [HUB-06_space_fitter.stl]
